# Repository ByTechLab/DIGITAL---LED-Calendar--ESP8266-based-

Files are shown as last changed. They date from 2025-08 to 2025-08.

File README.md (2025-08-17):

<div align="center">
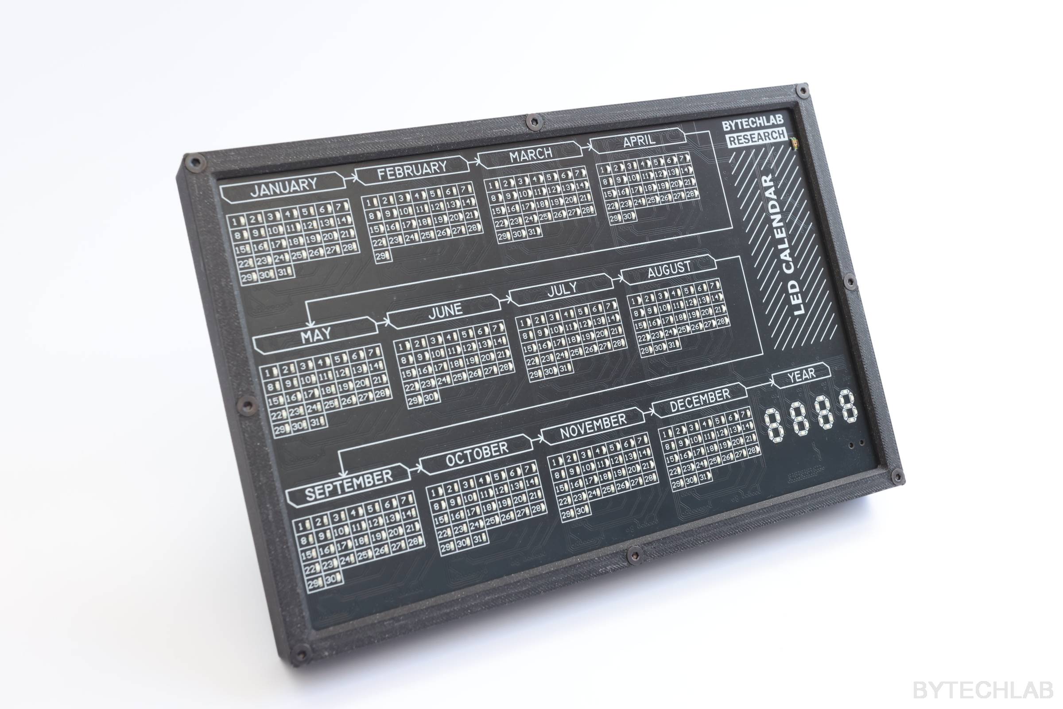
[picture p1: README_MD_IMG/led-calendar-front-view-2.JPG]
project photo
    
</div>

ESP8266 based LED calendar.

### Read more at BYTECHLAB:

<table style="width: 100%; border: none;" cellspacing="0" cellpadding="0" border="0">
  <tr>
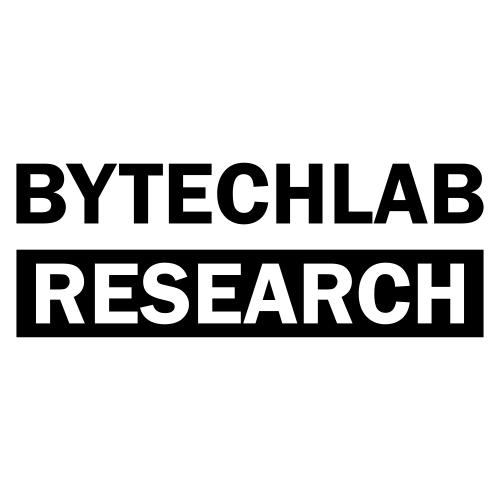
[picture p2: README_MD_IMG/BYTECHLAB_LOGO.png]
    <td></td>
    <td>https://bytechlab.com/2024/10/led-calendar-esp8266-based/</td>
  </tr>
</table>

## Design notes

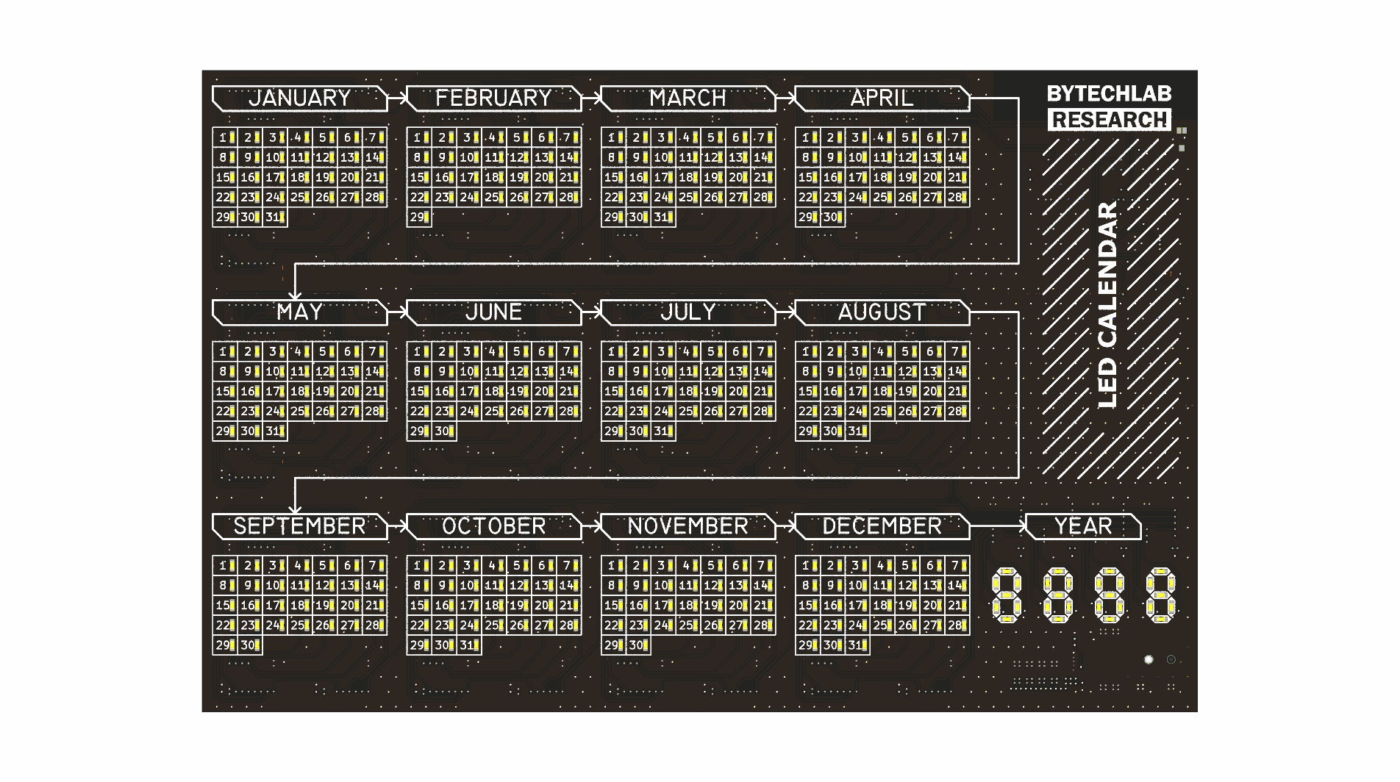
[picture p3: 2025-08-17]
PROJECT_FILES/ECAD/1_REV1_KICAD/_EXPORTED_RENDERS/PCB_LED_CALENDAR_TOP.png

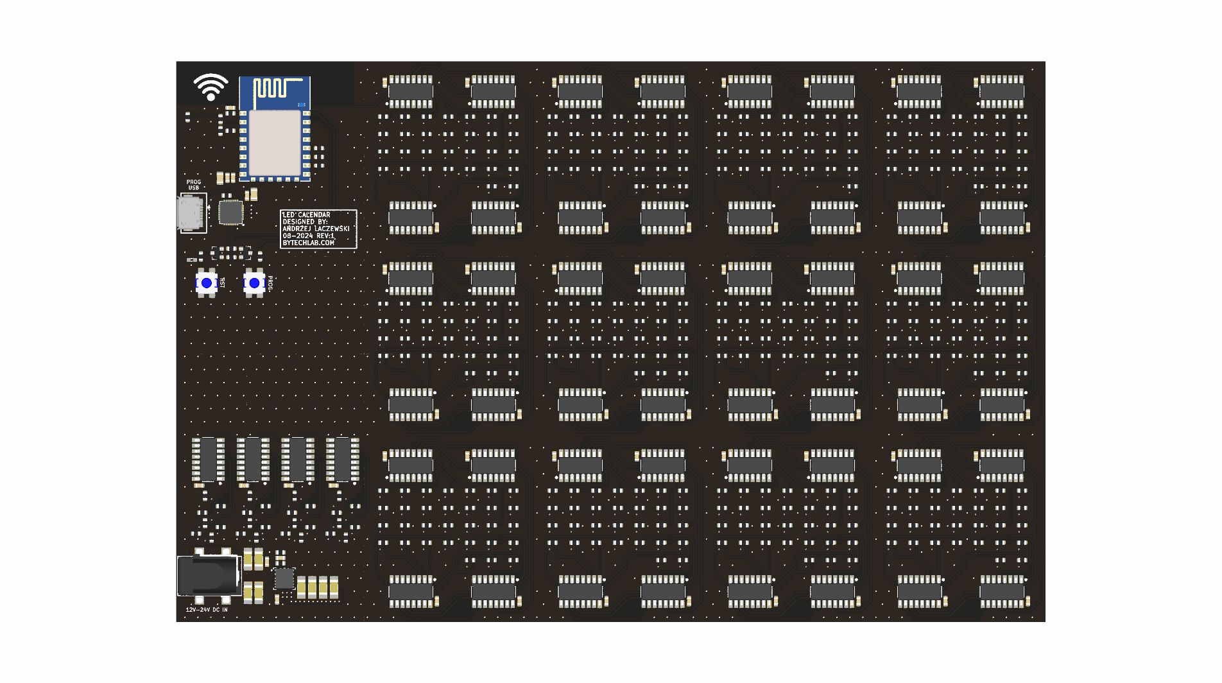
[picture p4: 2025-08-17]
PROJECT_FILES/ECAD/1_REV1_KICAD/_EXPORTED_RENDERS/PCB_LED_CALENDAR_BOTTOM.png

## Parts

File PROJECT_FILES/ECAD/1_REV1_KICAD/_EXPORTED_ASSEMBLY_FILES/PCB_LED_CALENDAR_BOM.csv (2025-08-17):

Reference | Qty | Manufacturer | Manufacturer Part Number | SCH_FOOTPRINT
C1,C5 | 2 | TDK | CGA4J1X7R1E475K125AC | 0805
C2,C3,C4,C6,C11,C13,C18,C19,C20,C21,C22,C23,C24,C25,C26,C27,C28,C29,C30,C31,C32,C33,C34,C35,C36,C37,C38,C39,C40,C41,C42,C43,C44,C45,C46,C47,C48,C49,C50,C51,C52,C53,C54,C55,C56,C57,C58,C59,C60,C61,C62,C63,C64,C65,C66,C67,C68,C69 | 58 | Samsung | CL10B104JB8NNNC | 0603
C7,C8,C9,C10,C14,C15 | 6 | Murata | GRT31CR61H106KE01L | 1206
C16,C17 | 2 | TDK | C3216X5R1E476M160AC | 1206
D1,D2,D3,D4,D5,D6,D7,D8,D9,D10,D11,D12,D13,D14,D15,D16,D17,D18,D19,D20,D21,D22,D23,D24,D25,D26,D27,D28,D29,D30,D31,D32,D33,D34,D35,D36,D37,D38,D39,D40,D41,D42,D43,D44,D45,D46,D47,D48,D49,D50,D51,D52,D53,D54,D55,D56,D57,D58,D59,D60,D61,D62,D63,D64,D65,D66,D67,D68,D69,D70,D71,D72,D73,D74,D75,D76,D77,D78,D79,D80,D81,D82,D83,D84,D85,D86,D87,D88,D89,D90,D91,D92,D93,D94,D95,D96,D97,D98,D99,D100,D101,D102,D103,D104,D105,D106,D107,D108,D109,D110,D111,D112,D113,D114,D115,D116,D117,D118,D119,D120,D121,D122,D123,D124,D125,D126,D127,D128,D129,D130,D131,D132,D133,D134,D135,D136,D137,D138,D139,D140,D141,D142,D143,D144,D145,D146,D147,D148,D149,D150,D151,D152,D153,D154,D155,D156,D157,D158,D159,D160,D161,D162,D163,D164,D165,D166,D167,D168,D169,D170,D171,D172,D173,D174,D175,D176,D177,D178,D179,D180,D181,D182,D183,D184,D185,D186,D187,D188,D189,D190,D191,D192,D193,D194,D195,D196,D197,D198,D199,D200,D201,D202,D203,D204,D205,D206,D207,D208,D209,D210,D211,D212,D213,D214,D215,D216,D217,D218,D219,D220,D221,D222,D223,D224,D225,D226,D227,D228,D229,D230,D231,D232,D233,D234,D235,D236,D237,D238,D239,D240,D241,D242,D243,D244,D245,D246,D247,D248,D249,D250,D251,D252,D253,D254,D255,D256,D257,D258,D259,D260,D261,D262,D263,D264,D265,D266,D267,D268,D269,D270,D271,D272,D273,D274,D275,D276,D277,D278,D279,D280,D281,D282,D283,D284,D285,D286,D287,D288,D289,D290,D291,D292,D293,D294,D295,D296,D297,D298,D299,D300,D301,D302,D303,D304,D305,D306,D307,D308,D309,D310,D311,D312,D313,D314,D315,D316,D317,D318,D319,D320,D321,D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 | 400 | Foshan NationStar Optoelectronics | NCD0603O1 | 0603
J1 | 1 | Molex | 47346-0001 | MICRO USB
MOD1 | 1 | Ai-thinker | ESP-12E | ESP-12E
P1 | 1 | GCT | DCJ250-05-A-K1-A | DC JACK
Q1,Q2 | 2 | FUXINSEMI | S8050 | SOT23
QL1 | 1 | Vishay Intertech | TEMT6000X01 | 1206
R1,R15 | 2 | Vishay | CRCW060310K0FKTA | 0603
R2 | 1 | Vishay | CRCW0603220KFKTABC | 0603
R3 | 1 | Royalohm | 0603SAF1003T5E | 0603
R4,R5,R6,R9,R11,R12,R13 | 7 | Yageo | RC0603FR-0712KL | 0603
R8,R10 | 2 | Yageo | RC0603FR-07470RL | 0603
R14 | 1 | Vishay | CRCW06031K00FKEA | 0603
R16 | 1 | Vishay | RV0603E2211BNT | 0603
R17,R18,R19,R20,R21,R22,R23,R24,R25,R26,R27,R28,R29,R30,R31,R32,R33,R34,R35,R36,R37,R38,R39,R40,R41,R42,R43,R44,R45,R46,R47,R48,R49,R50,R51,R52,R53,R54,R55,R56,R57,R58,R59,R60,R61,R62,R63,R64,R65,R66,R67,R68,R69,R70,R71,R72,R73,R74,R75,R76,R77,R78,R79,R80,R81,R82,R83,R84,R85,R86,R87,R88,R89,R90,R91,R92,R93,R94,R95,R96,R97,R98,R99,R100,R101,R102,R103,R104,R105,R106,R107,R108,R109,R110,R111,R112,R113,R114,R115,R116,R117,R118,R119,R120,R121,R122,R123,R124,R125,R126,R127,R128,R129,R130,R131,R132,R133,R134,R135,R136,R137,R138,R139,R140,R141,R142,R143,R144,R145,R146,R147,R148,R149,R150,R151,R152,R153,R154,R155,R156,R157,R158,R159,R160,R161,R162,R163,R164,R165,R166,R167,R168,R169,R170,R171,R172,R173,R174,R175,R176,R177,R178,R179,R180,R181,R182,R183,R184,R185,R186,R187,R188,R189,R190,R191,R192,R193,R194,R195,R196,R197,R198,R199,R200,R201,R202,R203,R204,R205,R206,R207,R208,R209,R210,R211,R212,R213,R214,R215,R216,R217,R218,R219,R220,R221,R222,R223,R224,R225,R226,R227,R228,R229,R230,R231,R232,R233,R234,R235,R236,R237,R238,R239,R240,R241,R242,R243,R244,R245,R246,R247,R248,R249,R250,R251,R252,R253,R254,R255,R256,R257,R258,R259,R260,R261,R262,R263,R264,R265,R266,R267,R268,R269,R270,R271,R272,R273,R274,R275,R276,R277,R278,R279,R280,R281,R282,R283,R284,R285,R286,R287,R288,R289,R290,R291,R292,R293,R294,R295,R296,R297,R298,R299,R300,R301,R302,R303,R304,R305,R306,R307,R308,R309,R310,R311,R312,R313,R314,R315,R316,R317,R318,R319,R320,R321,R322,R323,R324,R325,R326,R327,R328,R329,R330,R331,R332,R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 | 400 | Yageo | RC0603FR-07300RL | 0603
S1,S2 | 2 | BOURNS | 7914G-1-000E | SMD TACT SWITCH
U1 | 1 | SKYWORKS/SILICON LABS | CP2102N-A02-GQFN28R | QFN28
U2 | 1 | Texas Instruments | TPSM84209RKHT | QFN9_4.5x4
U3,U4,U5,U6,U7,U8,U9,U10,U11,U12,U13,U14,U15,U16,U17,U18,U19,U20,U21,U22,U23,U24,U25,U26,U27,U28,U29,U30,U31,U32,U33,U34,U35,U36,U37,U38,U39,U40,U41,U42,U43,U44,U45,U46,U47,U48,U49,U50,U51,U52,U53,U54 | 52 | Nexperia | 74HC595D,118 | SO16

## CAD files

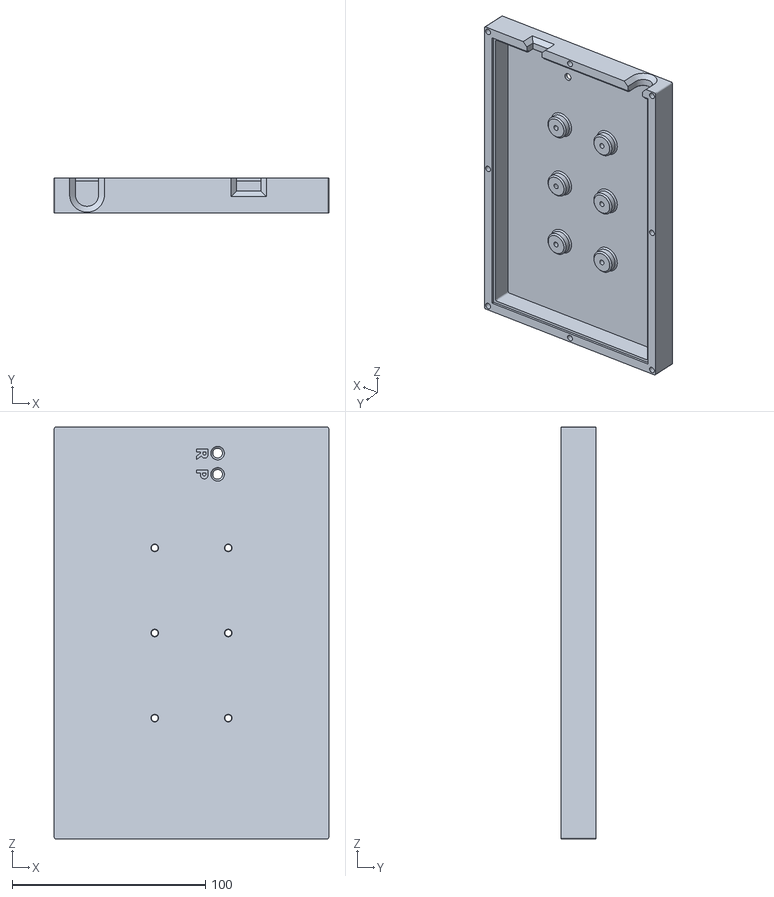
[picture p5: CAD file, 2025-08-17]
PROJECT_FILES/MCAD/2_REV2_KICAD/_STL_EXPORTED/3DP_PLA_Back_Cover.stl
142.0 x 18.0 x 213.0

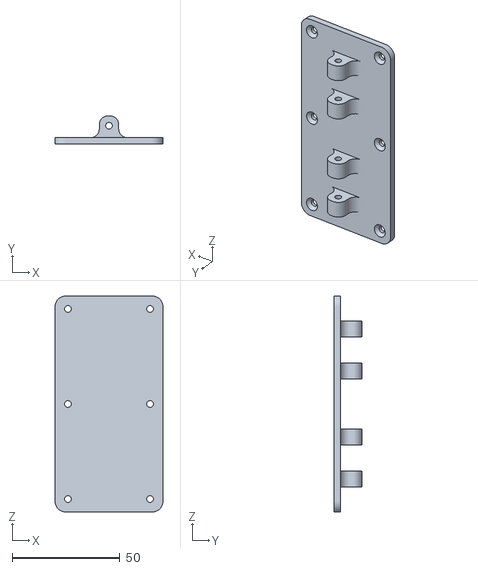
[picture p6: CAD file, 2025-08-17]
PROJECT_FILES/MCAD/2_REV2_KICAD/_STL_EXPORTED/3DP_PLA_Stand_Leg_Mount.stl
50.0 x 13.0 x 100.0

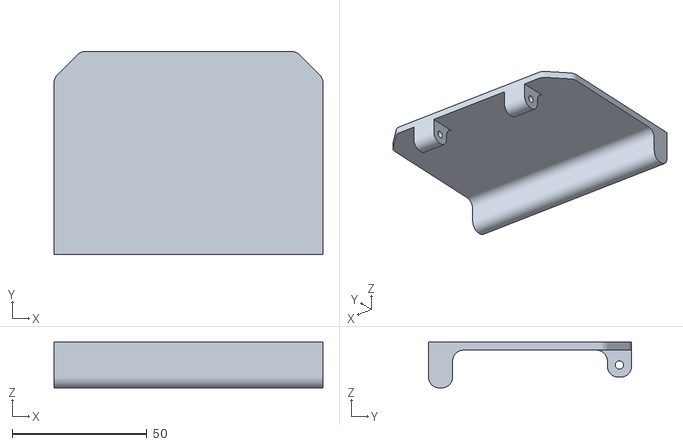
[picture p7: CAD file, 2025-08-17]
PROJECT_FILES/MCAD/2_REV2_KICAD/_STL_EXPORTED/3DP_PLA_Stand_Leg.stl
100.0 x 75.5 x 17.0

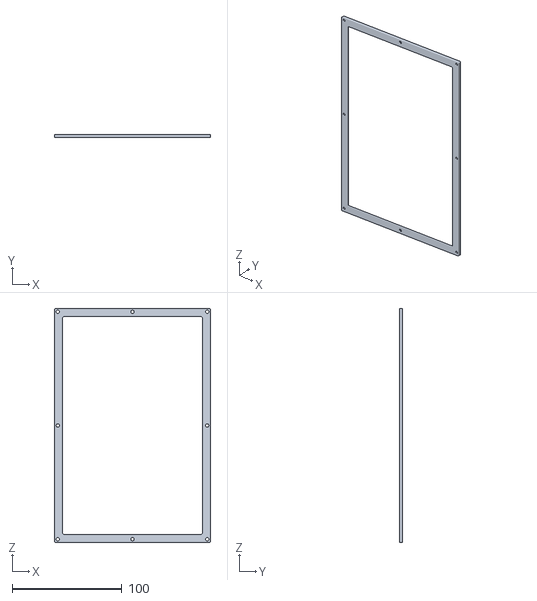
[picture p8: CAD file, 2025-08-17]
PROJECT_FILES/MCAD/2_REV2_KICAD/_STL_EXPORTED/3DP_PLA_Front_Mounting_Bracket.stl
142.0 x 3.00 x 213.0

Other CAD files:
PROJECT_FILES/MCAD/2_REV2_KICAD/ASSEMBLY_MAIN_REVA/3DP_PLA_Back_Cover.ipt
PROJECT_FILES/MCAD/2_REV2_KICAD/ASSEMBLY_MAIN_REVA/3DP_PLA_Front_Mounting_Bracket.ipt
PROJECT_FILES/MCAD/2_REV2_KICAD/ASSEMBLY_MAIN_REVA/3DP_PLA_Stand_Leg.ipt
PROJECT_FILES/MCAD/2_REV2_KICAD/ASSEMBLY_MAIN_REVA/3DP_PLA_Stand_Leg_Mount.ipt
PROJECT_FILES/MCAD/2_REV2_KICAD/ASSEMBLY_MAIN_REVA/ASSEMBLY_Main.iam
PROJECT_FILES/MCAD/2_REV2_KICAD/__CONTENT_CENTER_PARTS/DIN 125-2 A/DIN 125-2 - A 3,2A.ipt
PROJECT_FILES/MCAD/2_REV2_KICAD/__CONTENT_CENTER_PARTS/DIN 7991(2)/DIN 7991 - M3x12.ipt
PROJECT_FILES/MCAD/2_REV2_KICAD/__CONTENT_CENTER_PARTS/DIN 7991(2)/DIN 7991 - M3x8.ipt
PROJECT_FILES/MCAD/2_REV2_KICAD/__CONTENT_CENTER_PARTS/DIN 934/DIN 934 - M3 x 0,5.ipt
PROJECT_FILES/MCAD/2_REV2_KICAD/__CONTENT_CENTER_PARTS/ISO 7380-1/ISO 7380-1 - M3 x 30.ipt
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

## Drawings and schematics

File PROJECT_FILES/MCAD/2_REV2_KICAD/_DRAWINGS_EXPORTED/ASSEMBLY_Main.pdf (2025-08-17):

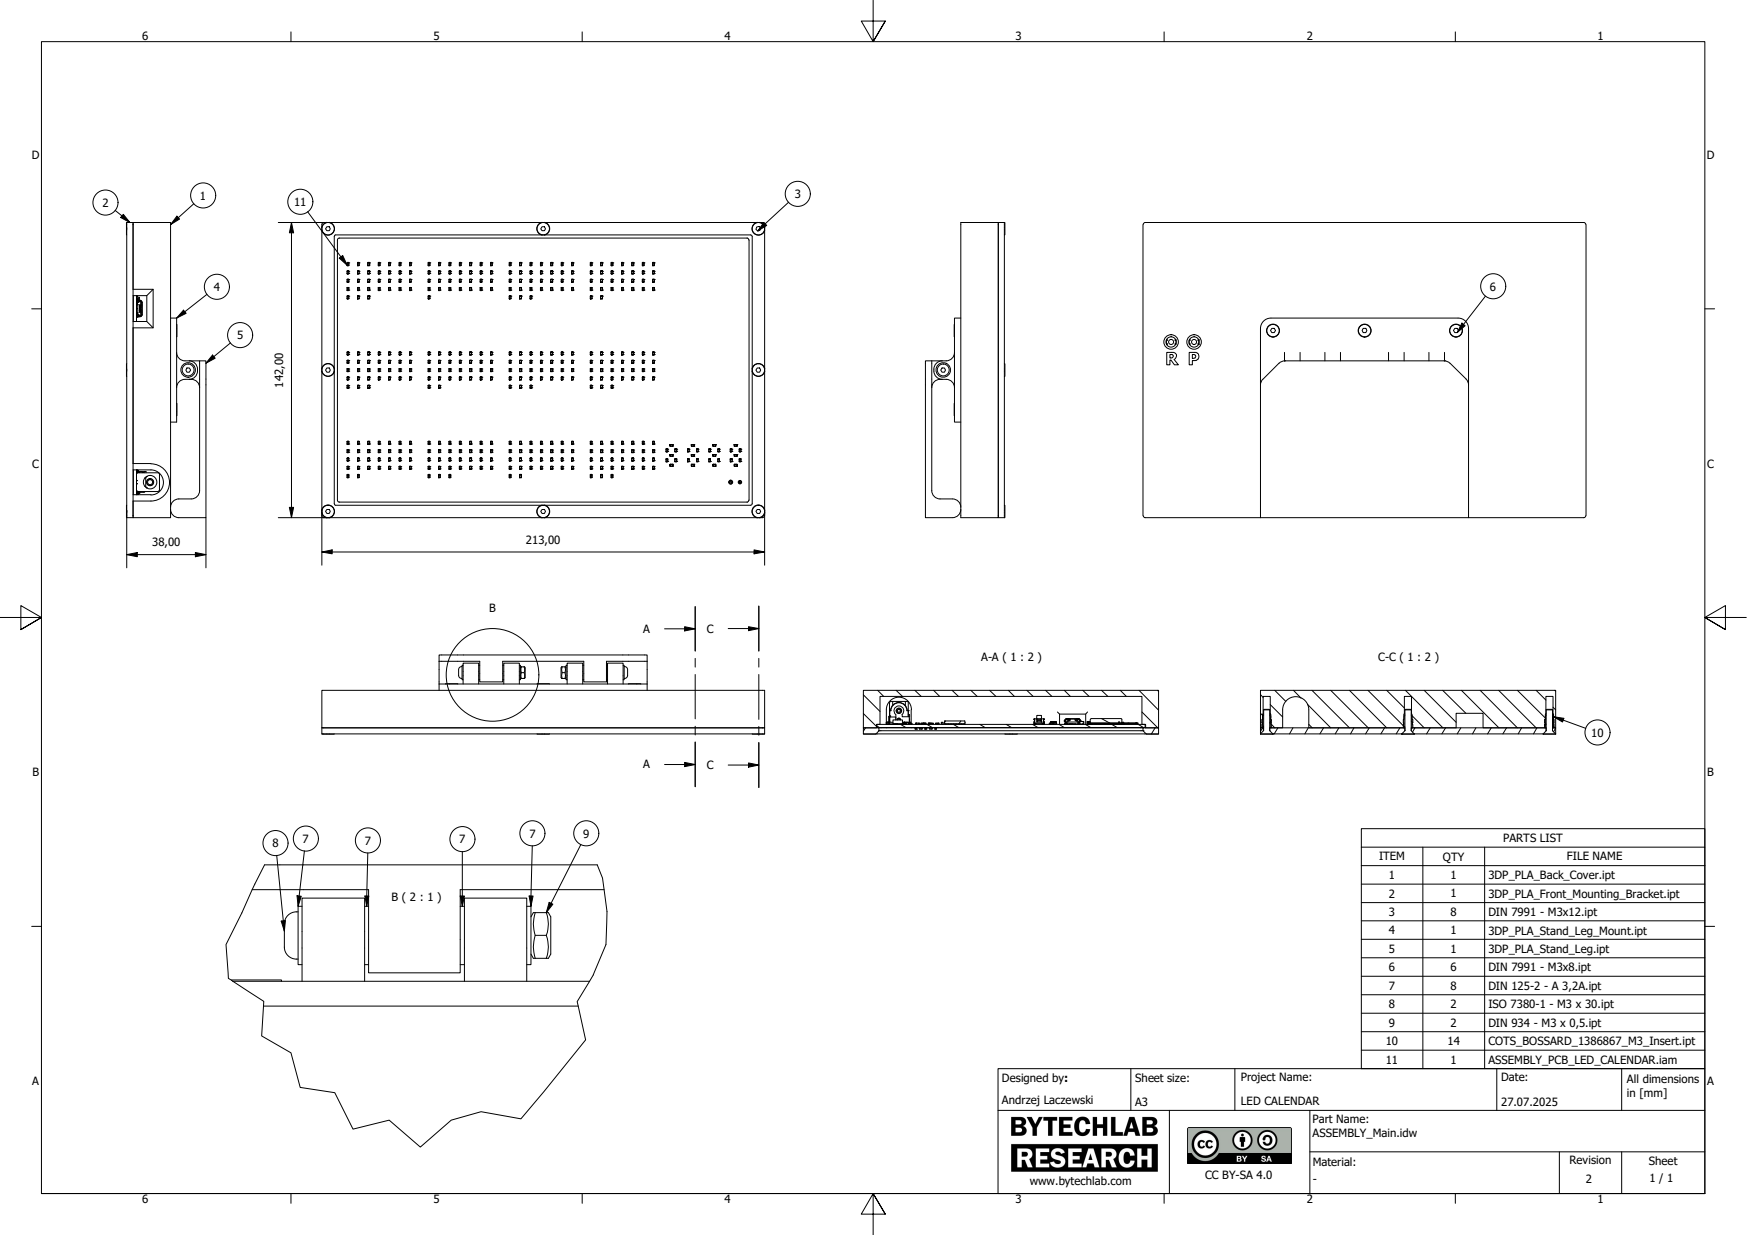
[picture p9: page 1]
PARTS LIST; ITEM; QTY; FILE NAME; DIN 7991 - M3x12.ipt; DIN 7991 - M3x8.ipt; DIN 125-2 - A 3,2A.ipt; ISO 7380-1 - M3 x 30.ipt; DIN 934 - M3 x 0,5.ipt; Andrzej Laczewski; Designed by:; Sheet size:; Date:; Part Name:; All dimensions in [mm]; Project Name:; LED CALENDAR

www.bytechlab.com

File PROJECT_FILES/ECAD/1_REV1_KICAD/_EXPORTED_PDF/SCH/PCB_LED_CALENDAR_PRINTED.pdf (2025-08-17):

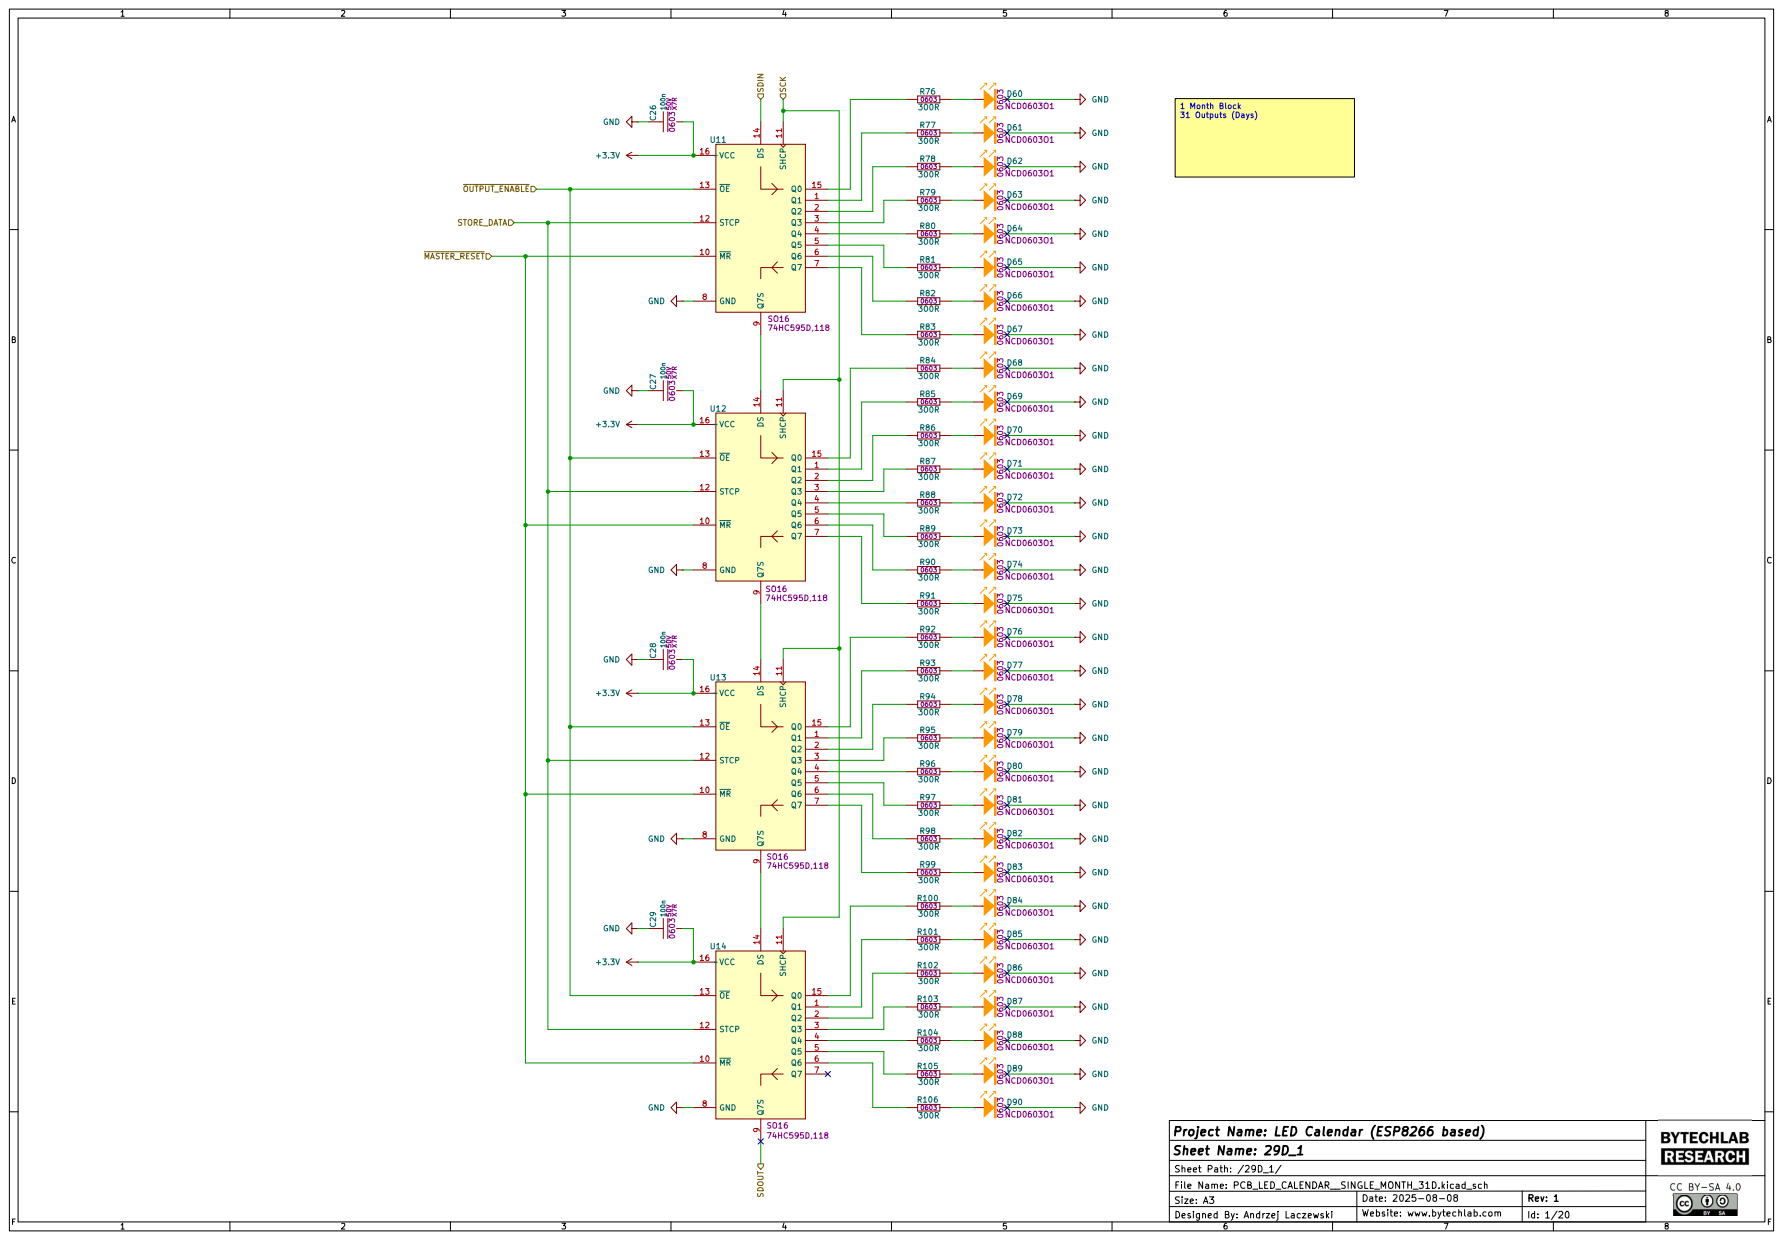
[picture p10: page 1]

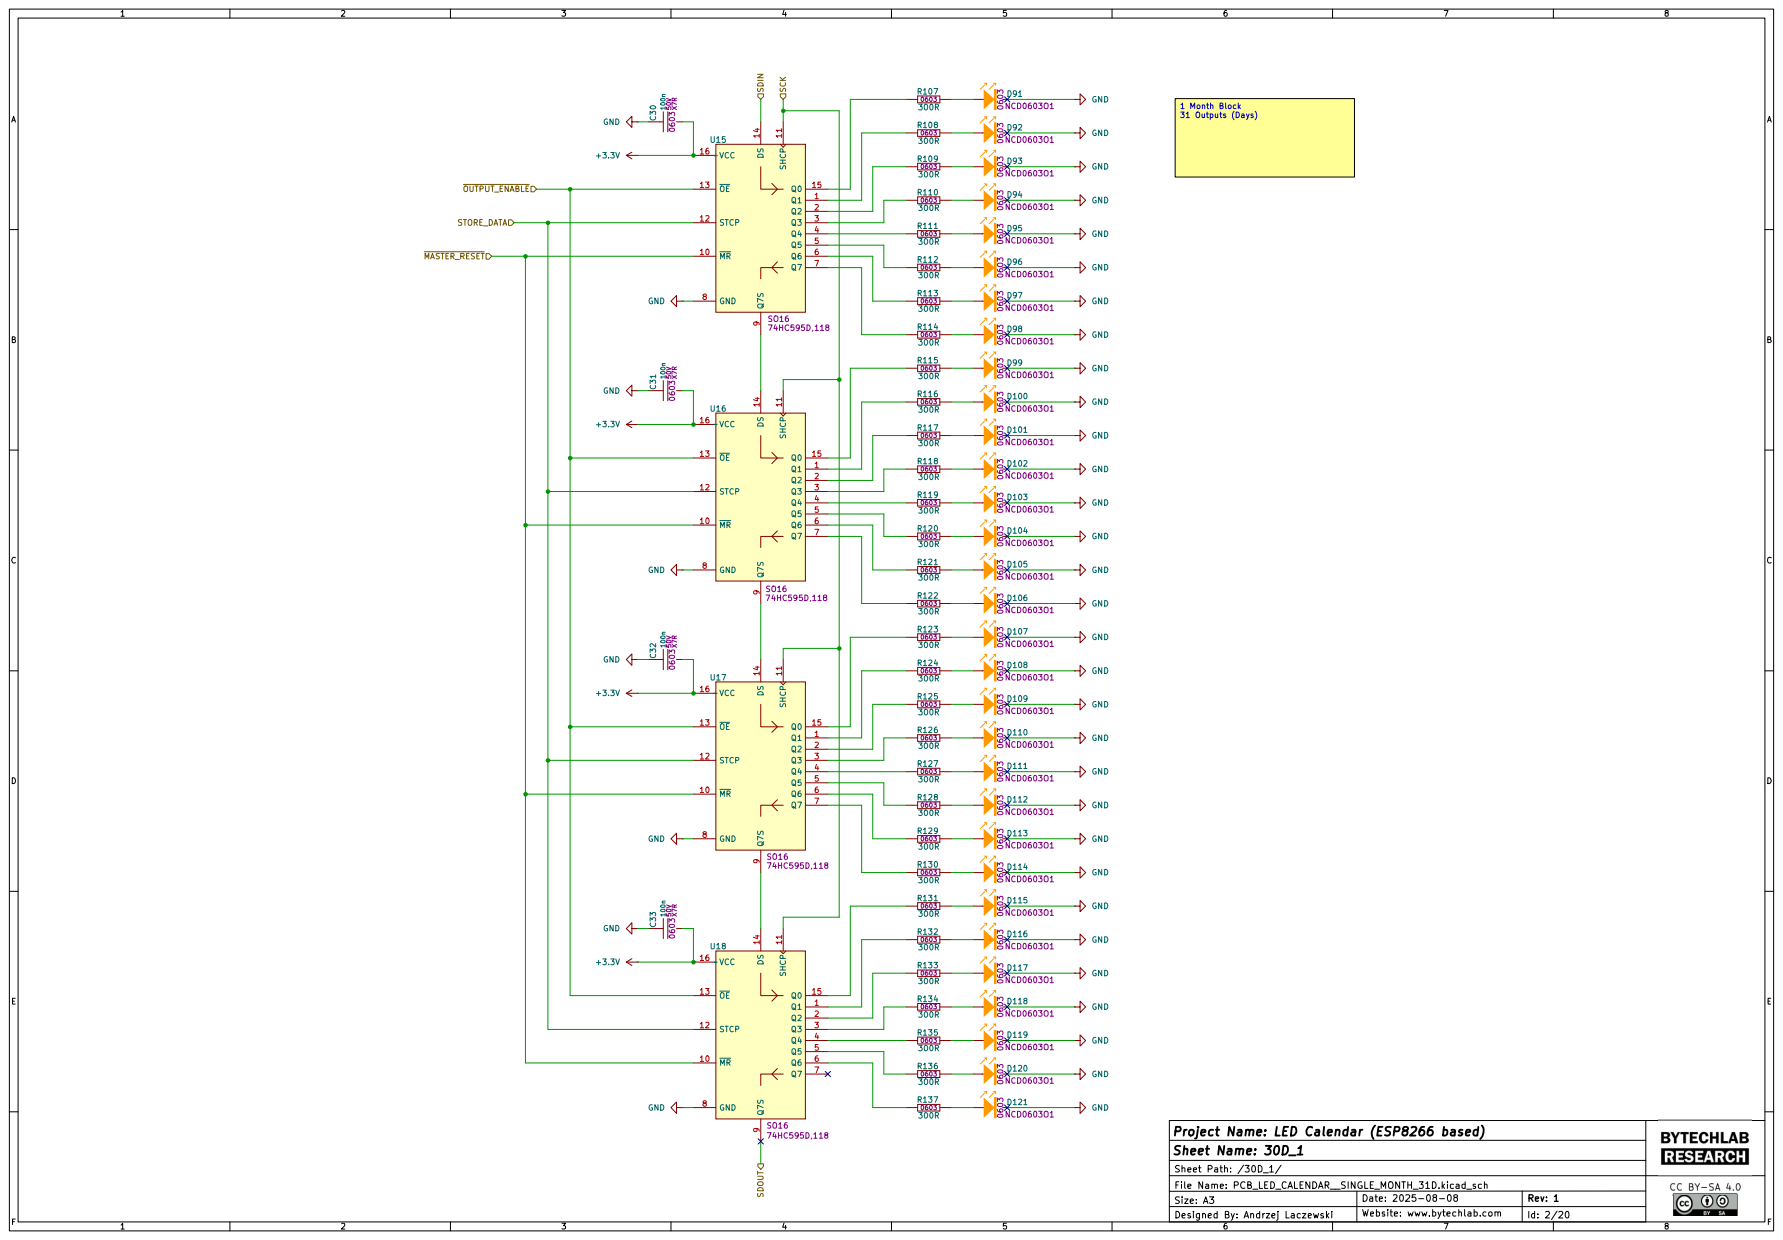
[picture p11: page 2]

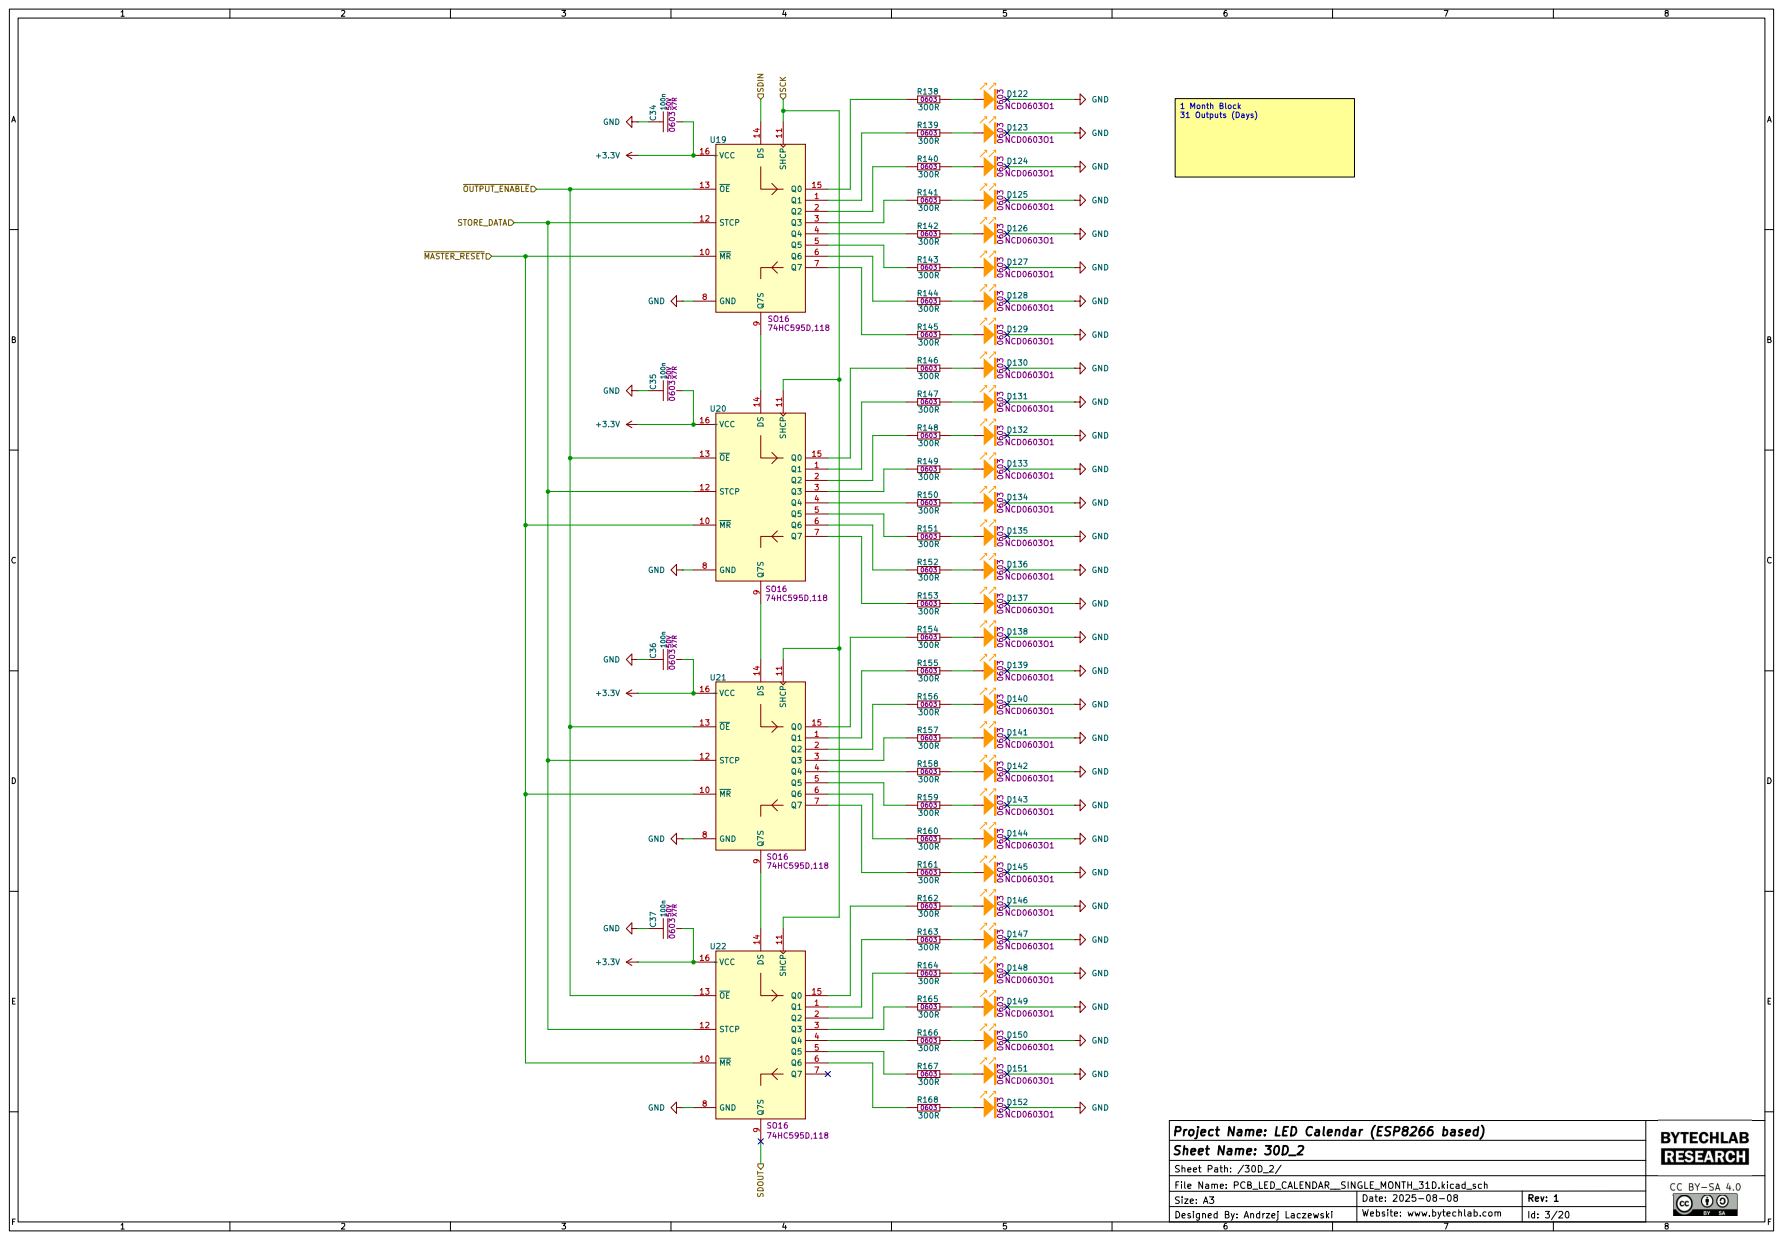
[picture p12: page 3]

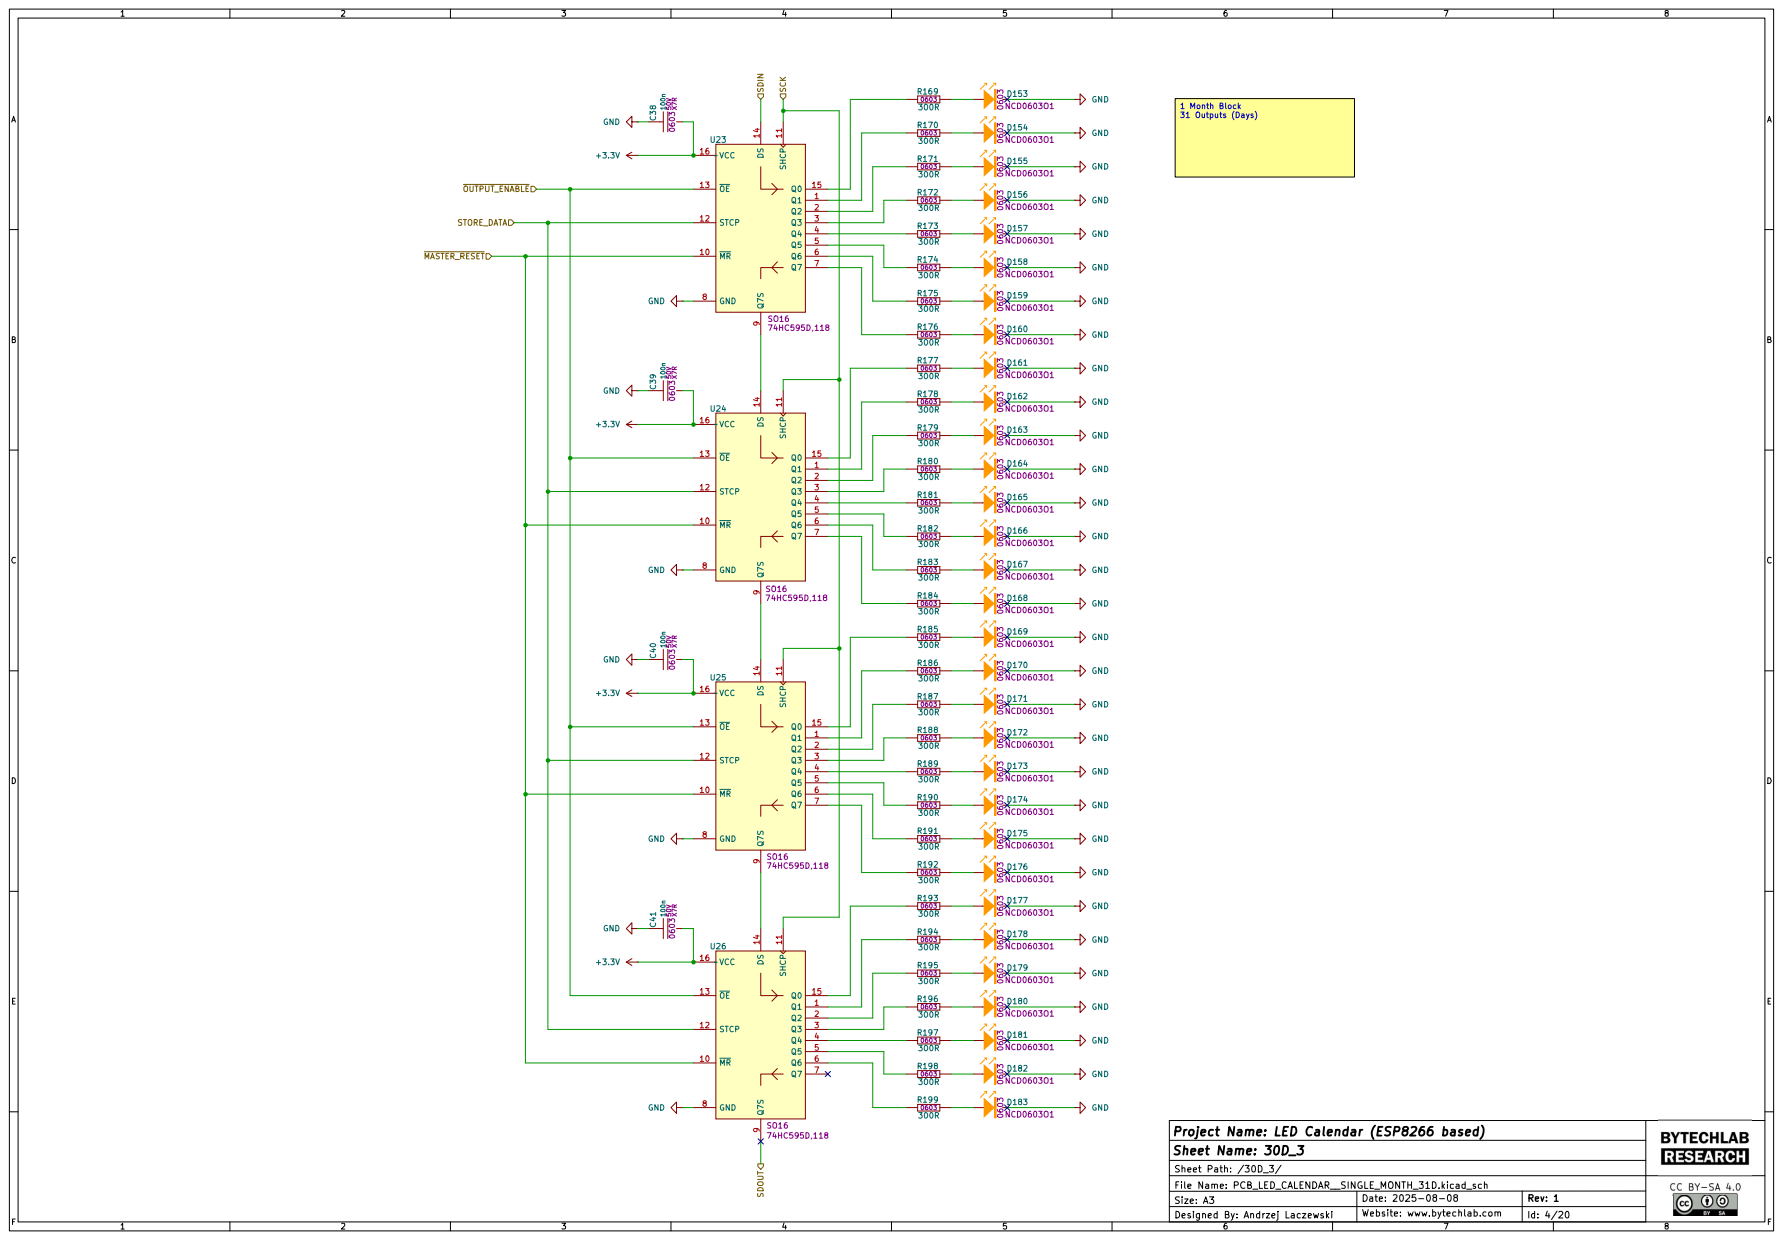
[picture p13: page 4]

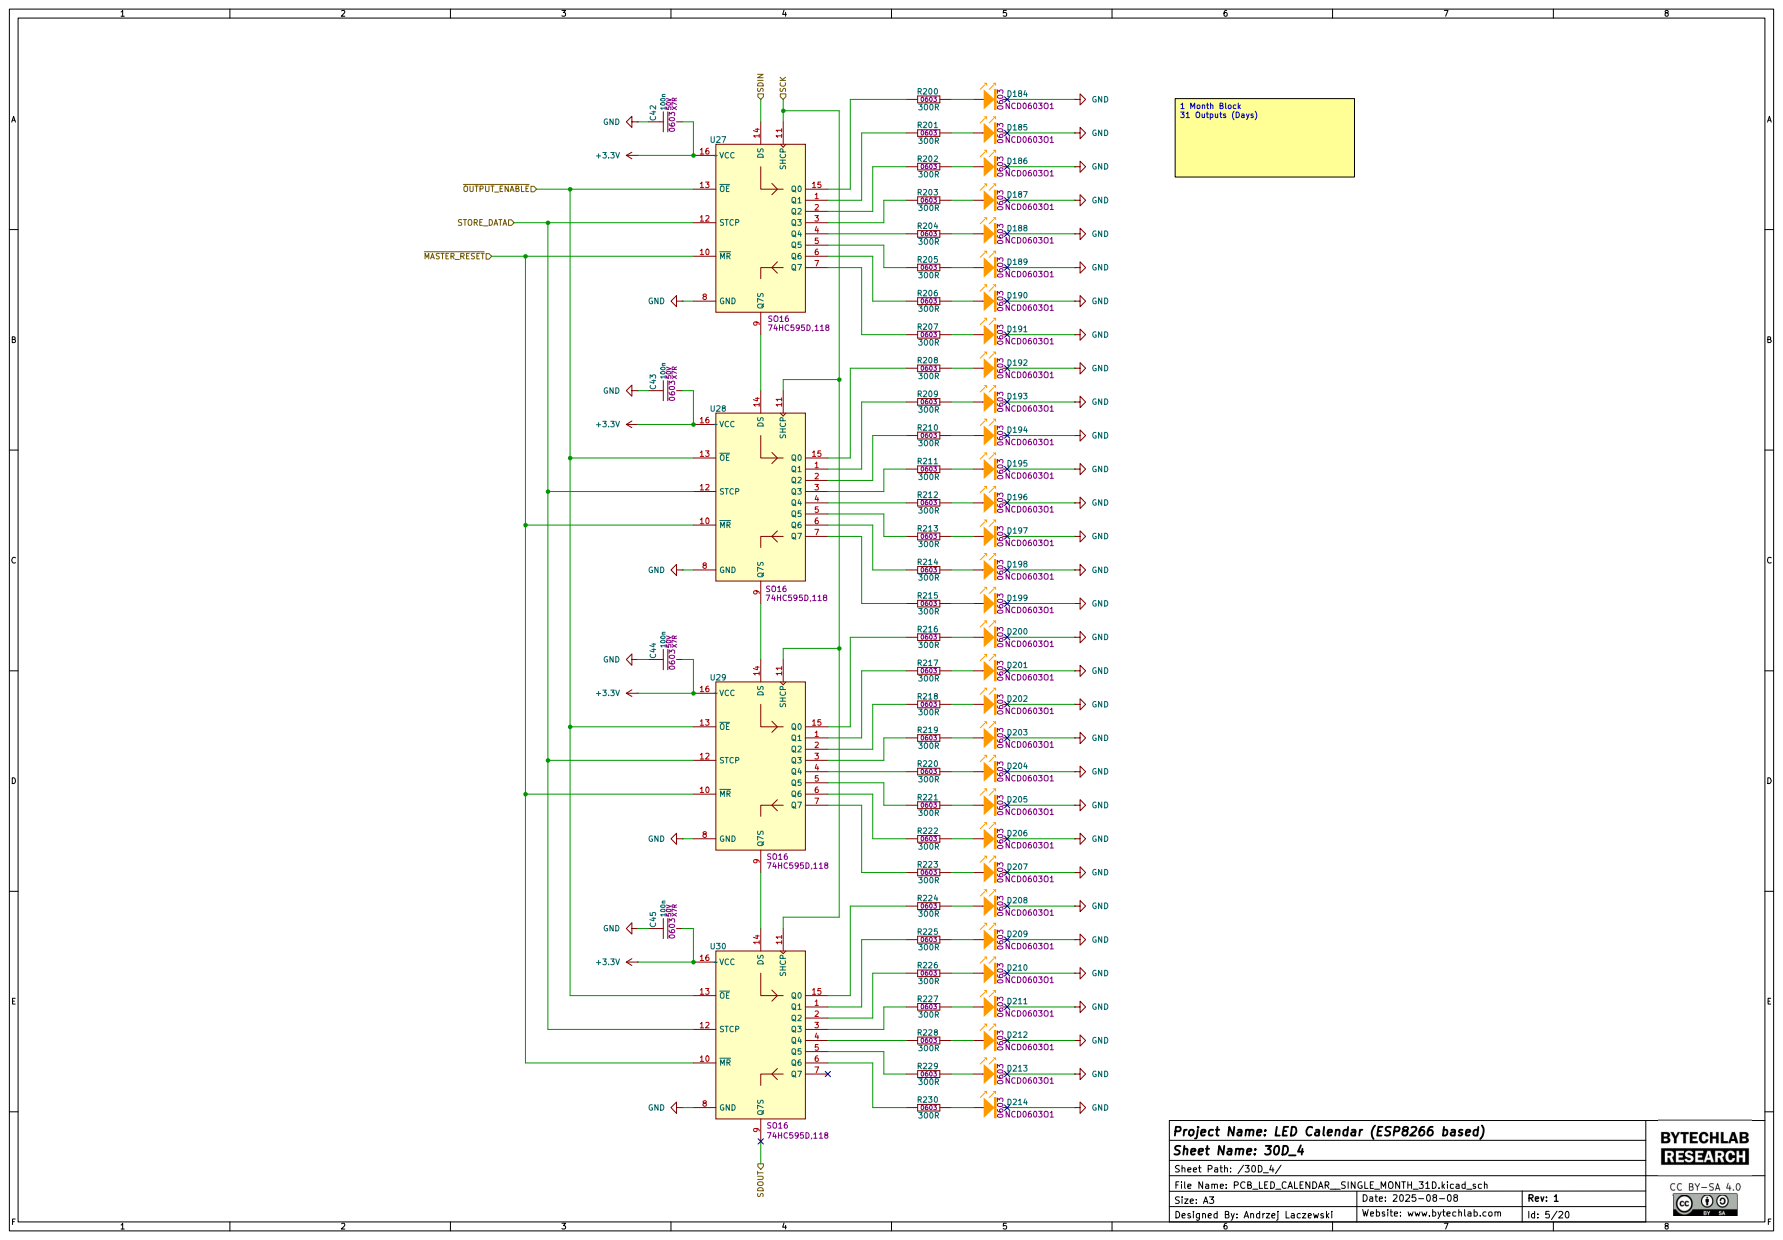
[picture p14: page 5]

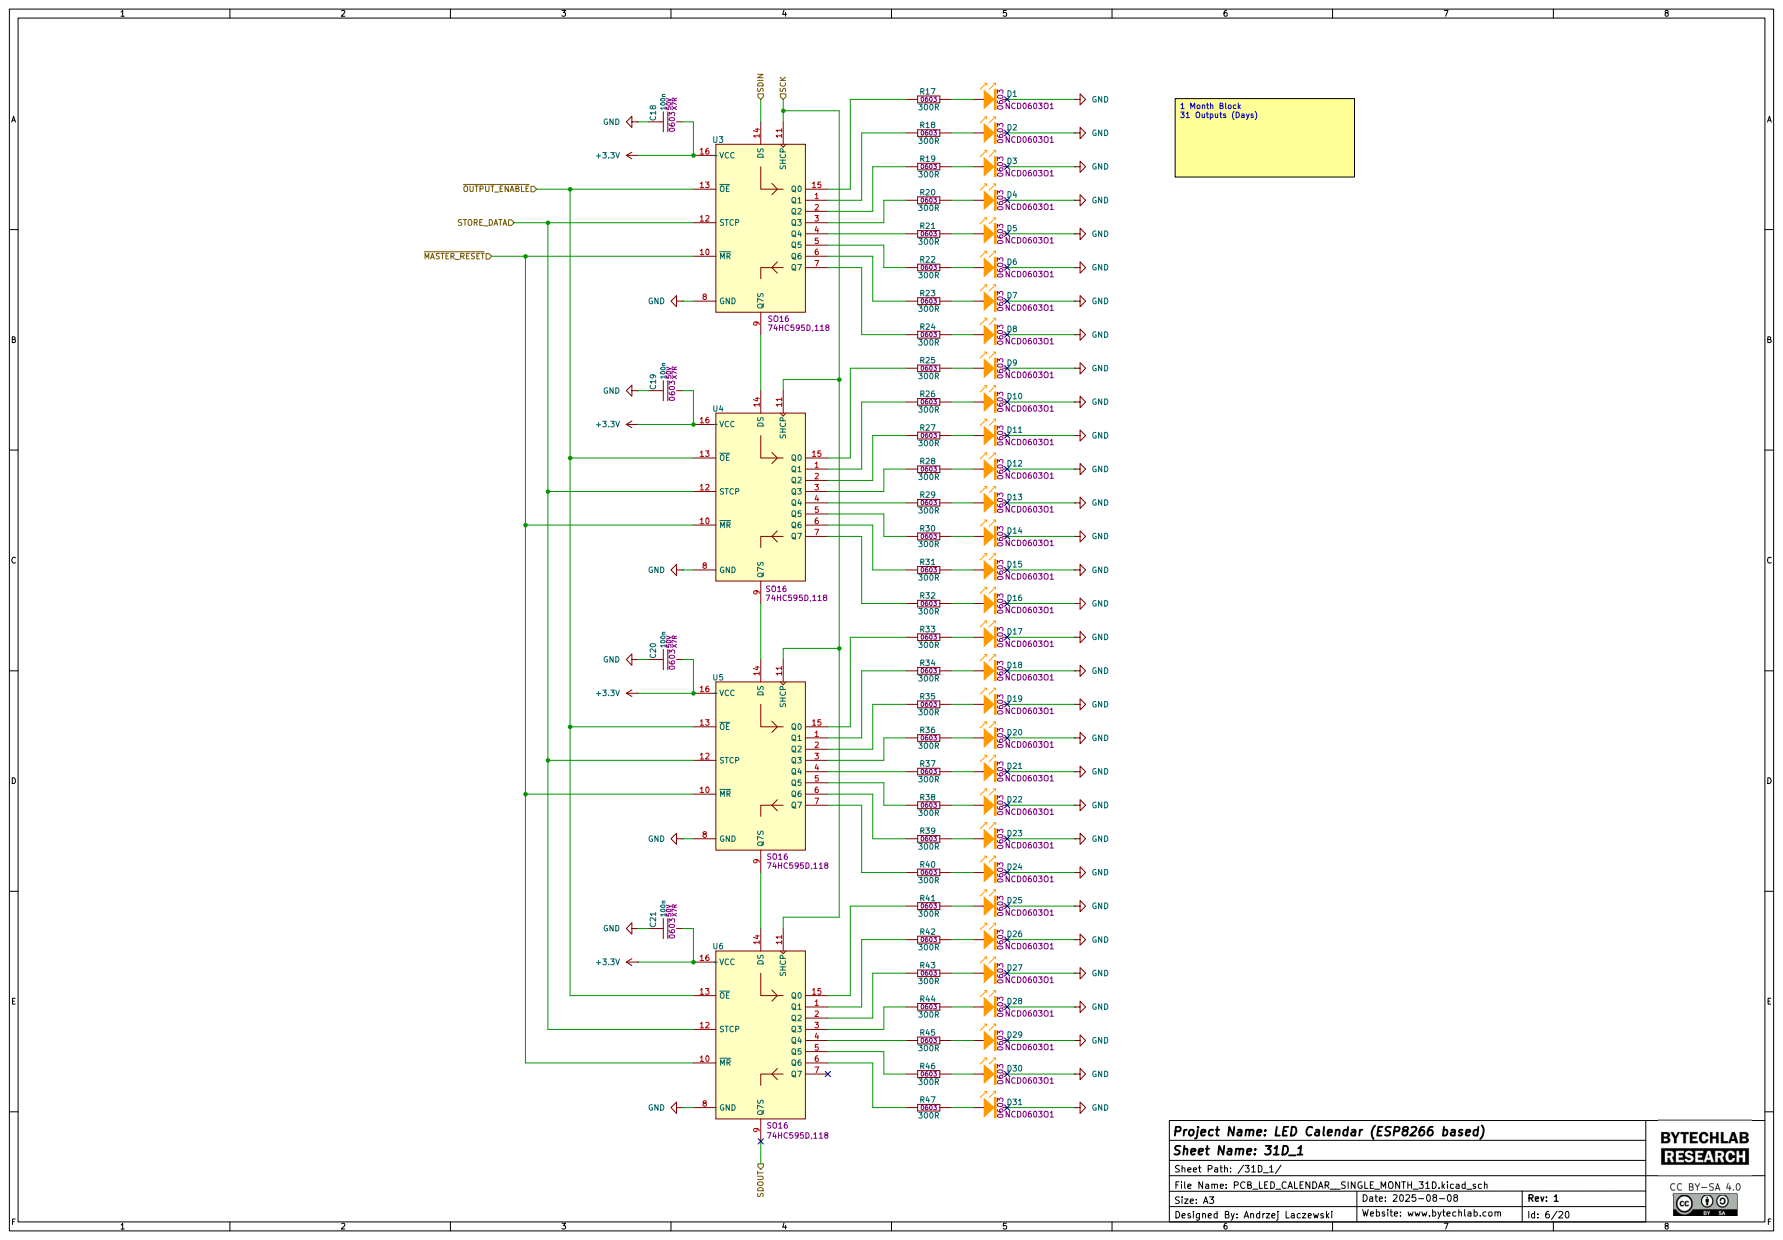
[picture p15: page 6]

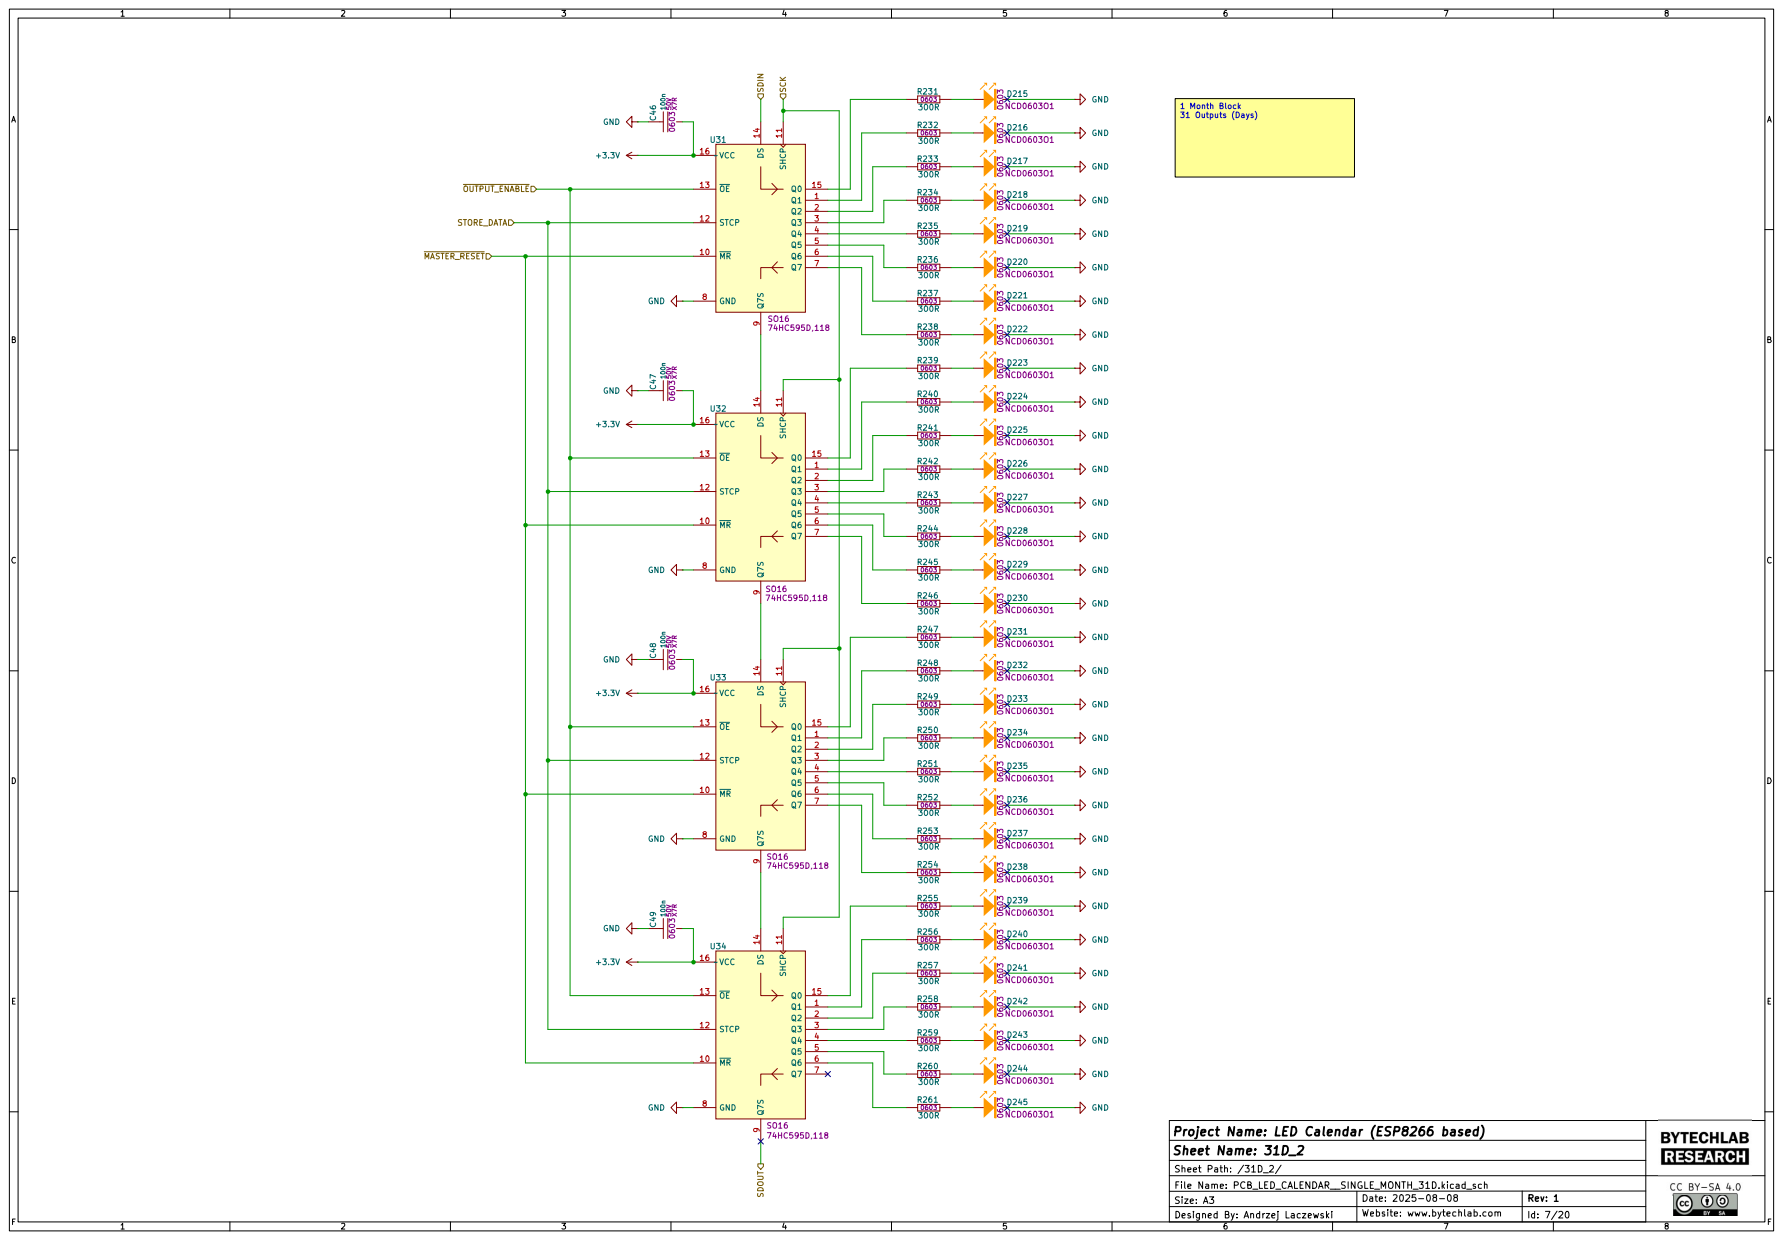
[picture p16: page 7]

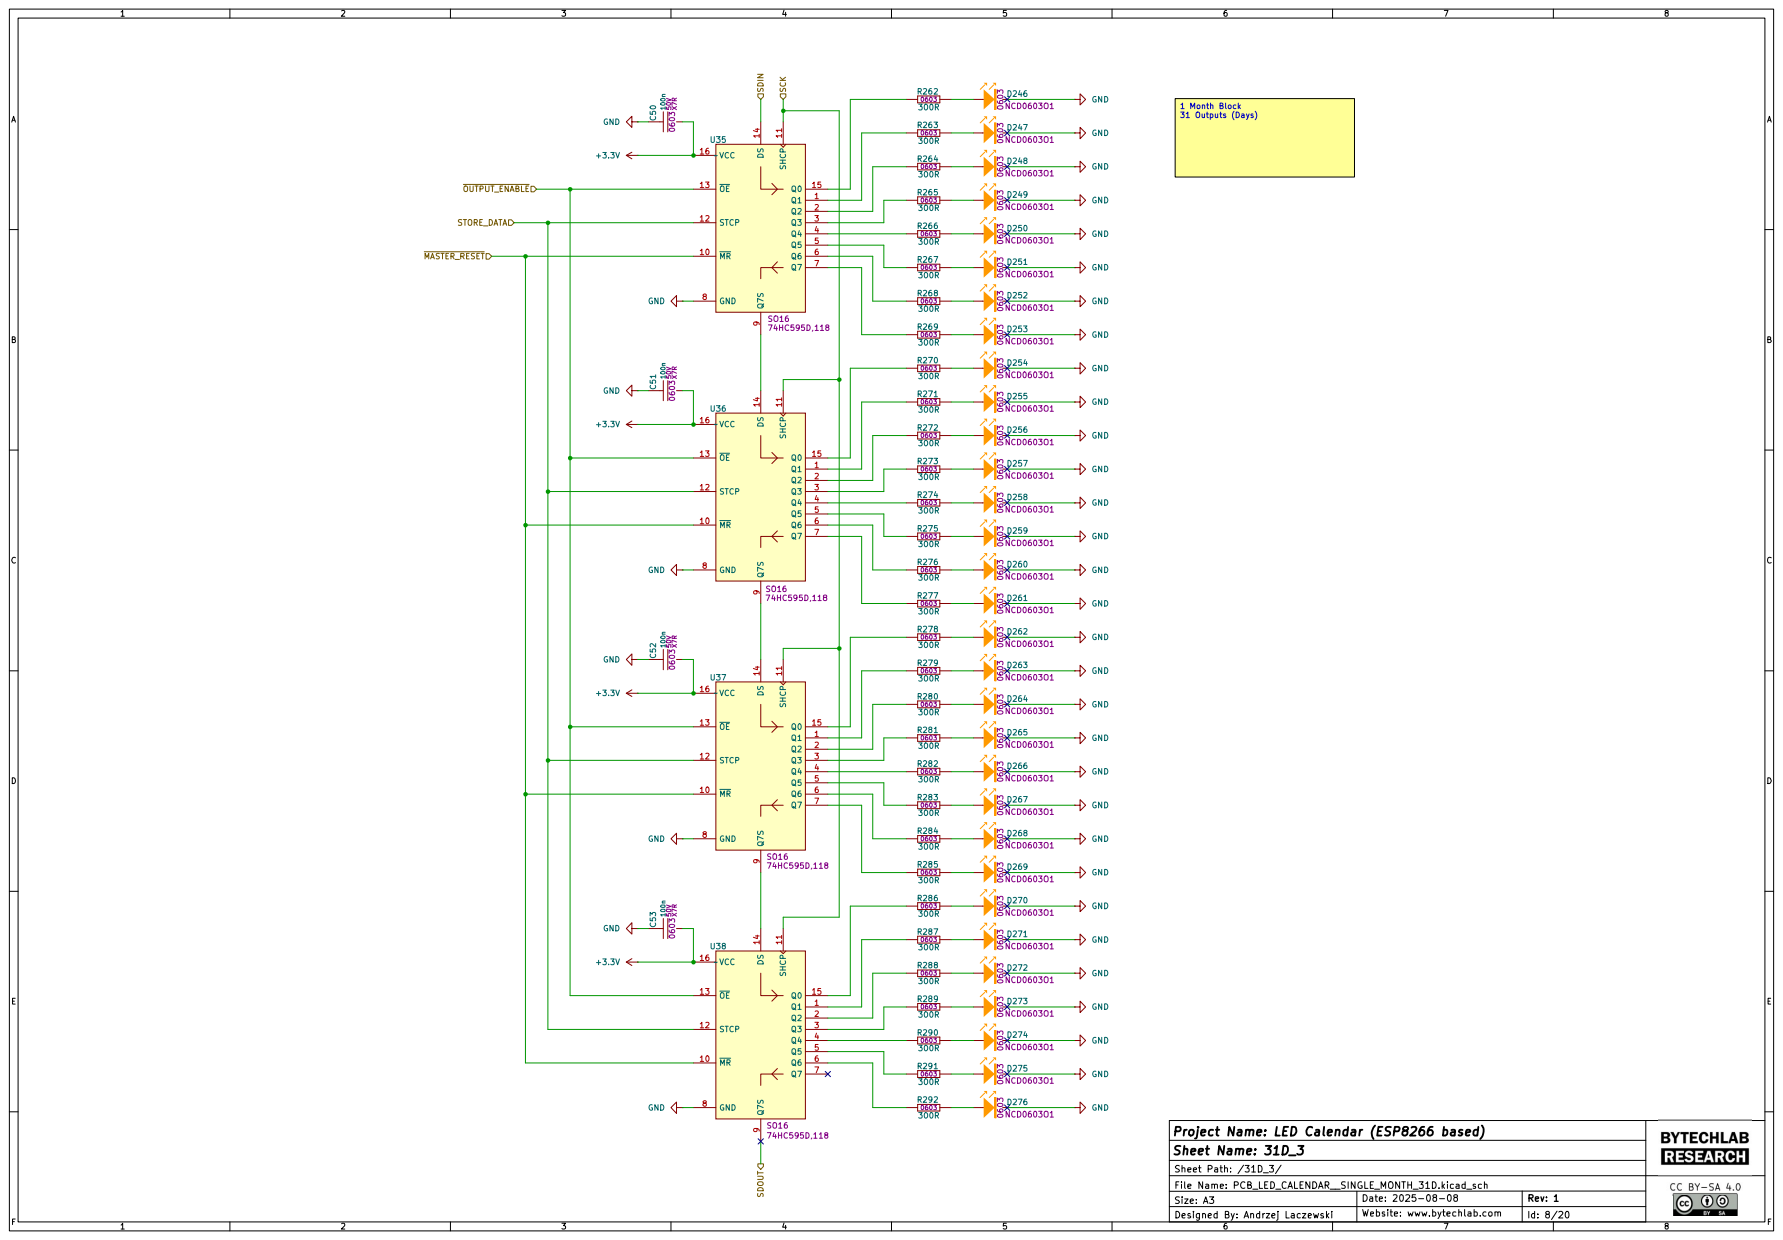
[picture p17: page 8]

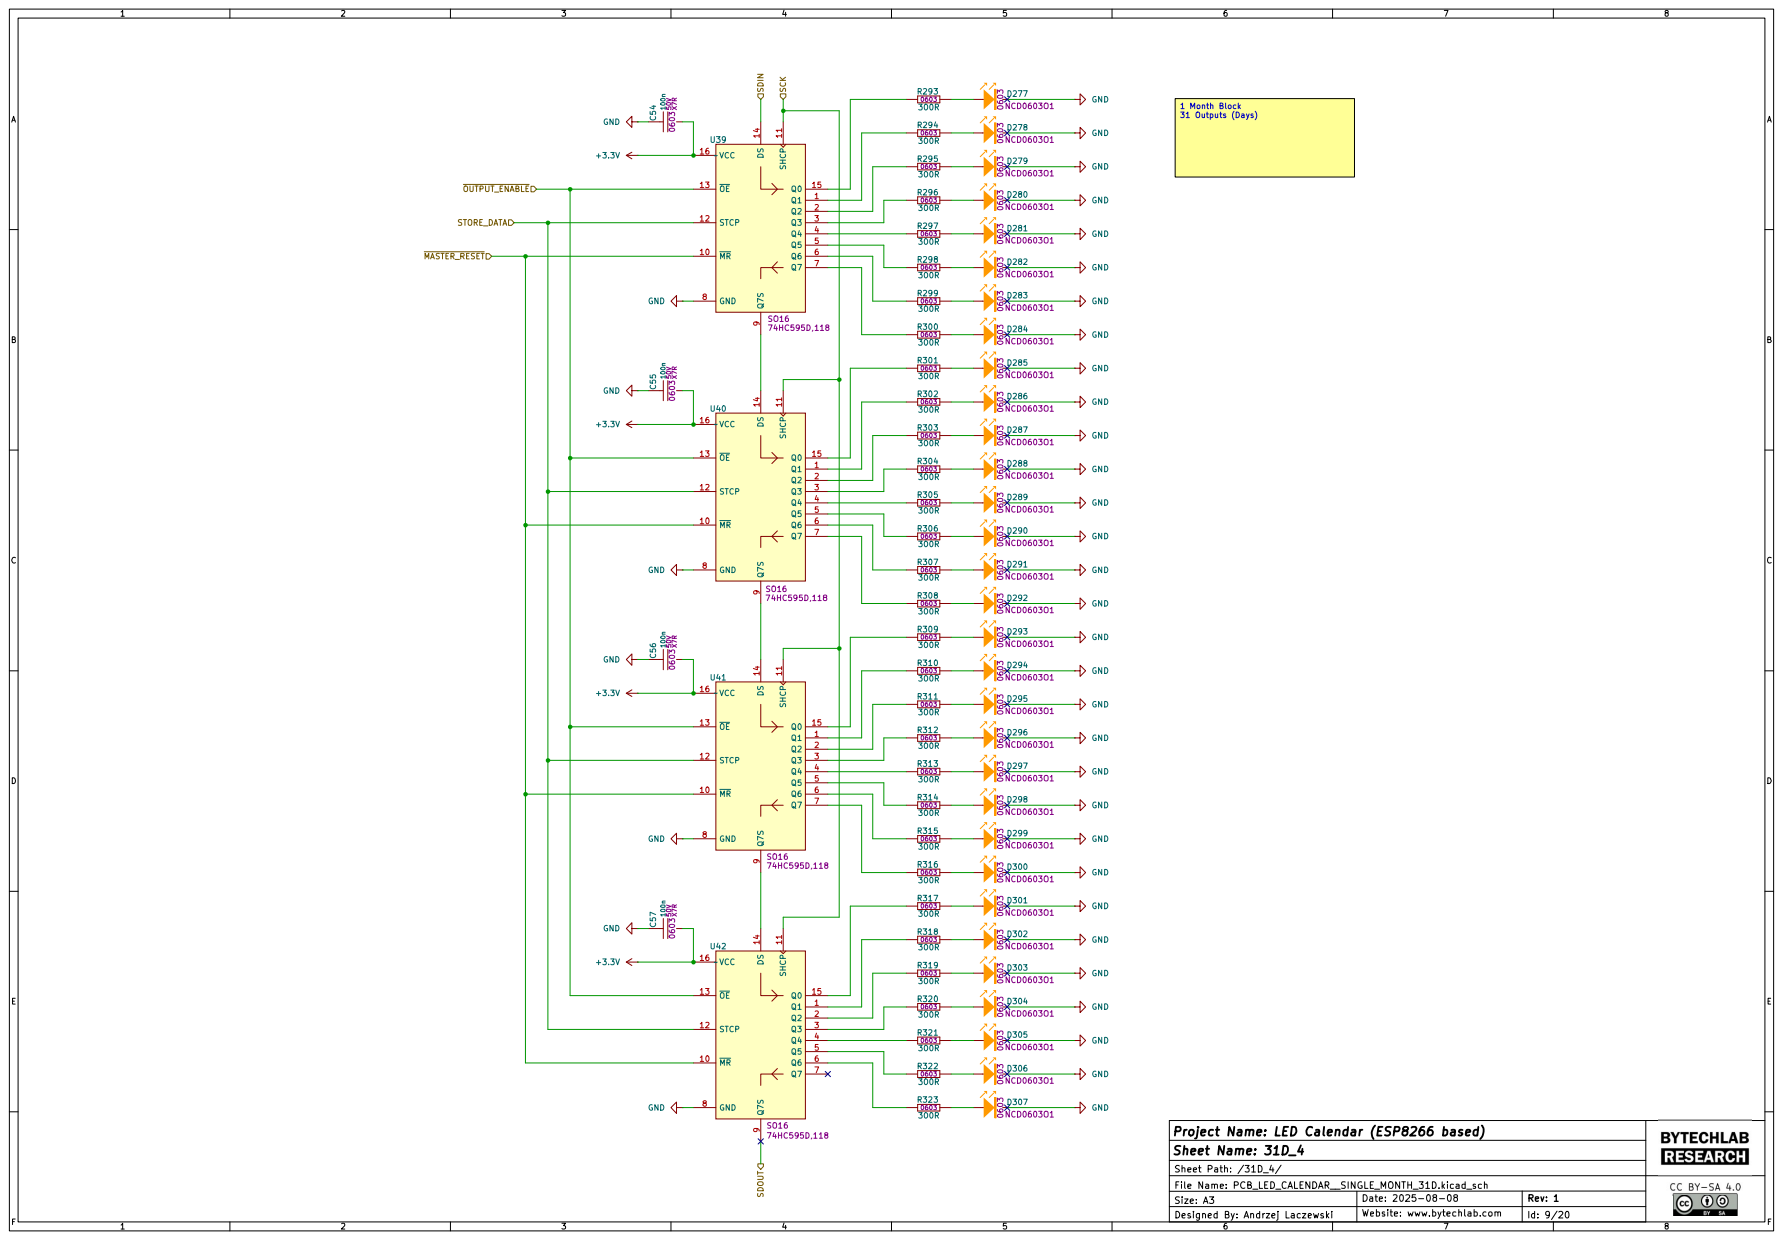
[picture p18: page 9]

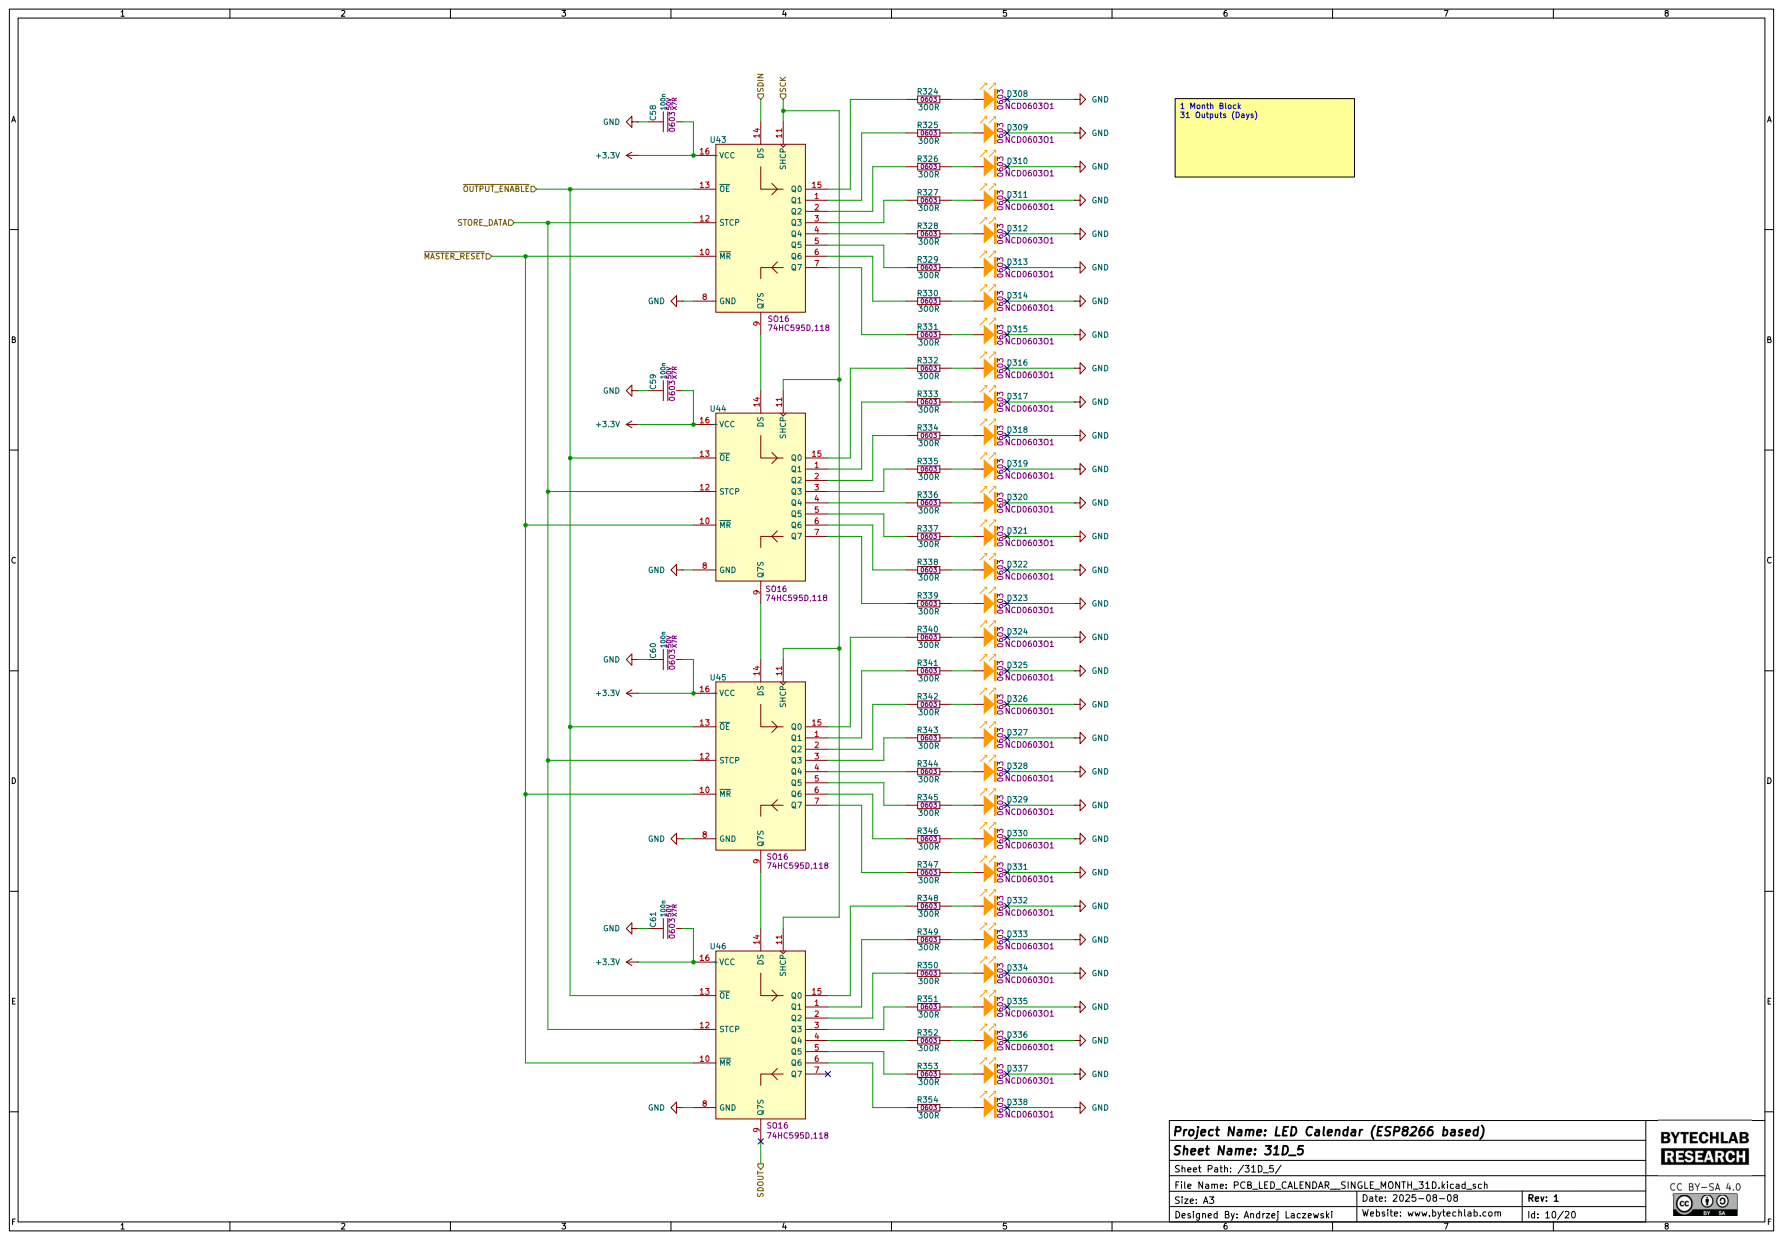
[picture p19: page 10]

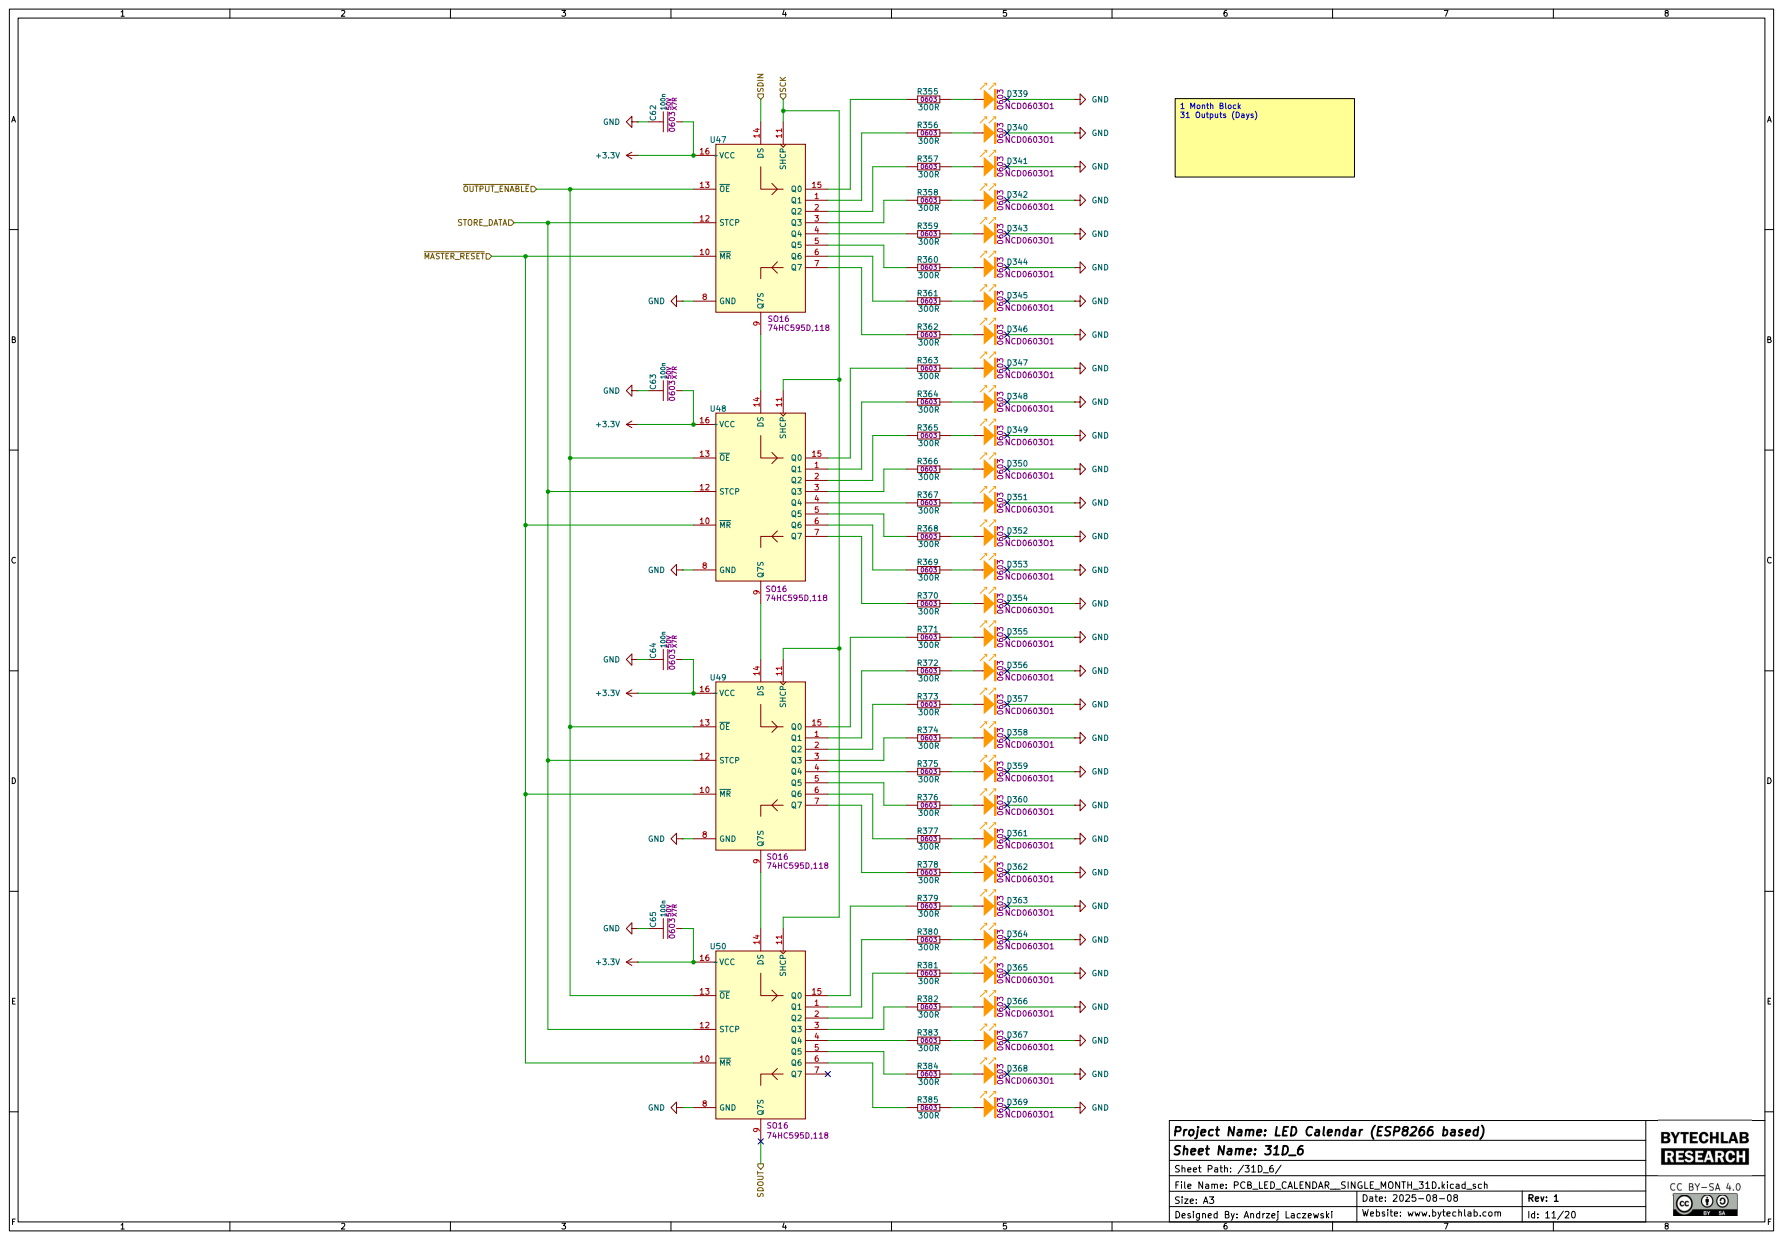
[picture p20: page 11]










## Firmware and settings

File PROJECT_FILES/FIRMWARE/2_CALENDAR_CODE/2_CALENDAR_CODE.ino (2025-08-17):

#include <ESP8266WiFi.h>
#include <NTPClient.h>
#include <WiFiUdp.h>
#include <include/WiFiState.h>

// -------- TODO -------->
// * Reduce NTP request frequency - day change prediction algorithm,
// * Compile & Libraries & Upload instructions,

// ---------------- NTP ---------------->
// Replace with your network credentials
const char *ssid     = "YOUR_SSID";
const char *password = "YOUR_PASSWD";
// Set offset time in seconds to adjust for your timezone, for example:
// GMT +1 = 3600
// GMT +8 = 28800
// GMT -1 = -3600
// GMT 0 = 0
const unsigned int NTP_Timezone_Offset = 7200; //(GMT +2)

// Define NTP Client to get time
WiFiUDP ntpUDP;
NTPClient timeClient(ntpUDP, "pool.ntp.org");

unsigned int NTP_Check_Counter = 0;
#define NTP_CHECK_EVERY_N_LOOPS 30 // 60 seconds
// ---------------- NTP ----------------<

// ---------------- LED CALENDAR ---------------->
#define LED_CALENDAR_MAX_BRIGHTNESS 230
#define LED_CALENDAR_MIN_BRIGHTNESS 254

#define PIN_LED_SCK 14
#define PIN_LED_SDOUT 13
#define PIN_LED_OE 12
#define PIN_LED_STORE_DAT 5
#define PIN_LED_MASTER_RST 4

#define SHIFT_REG_SERIAL_HALF_PERIOD 25 // 25us -> 20 kHz

unsigned int LED_Calendar_Month = 1;
unsigned int LED_Calendar_Day = 1;
unsigned int LED_Calendar_Year = 0;

unsigned int LED_Calendar_Month_old = 1;
unsigned int LED_Calendar_Day_old = 1;
unsigned int LED_Calendar_Year_old = 0;

uint8_t LED_Calendar_Year_Digit_LUT [10] = 
{
    0b11111100, // 0
    0b01100000, // 1
    0b11011010, // 2
    0b11110010, // 3
    0b01100110, // 4
    0b10110110, // 5
    0b10111110, // 6
    0b11100000, // 7
    0b11111110, // 8
    0b11110110, // 9
};
// ---------------- LED CALENDAR ----------------<

void setup() 
{
  // Initialize Serial Monitor
  Serial.begin(115200);

  Serial.println("<--------- LED CALENDAR STARTUP --------->");

  LED_Calendar_Setup();
  LED_Calendar_Check_Ambient_Light();

  LED_Calendar_Clear_All_Leds();
  LED_Calendar_Startup_Animation();
  LED_Calendar_Clear_All_Leds();

  NTP_Setup();
  NTP_Update_Time_Variables();
}

void loop()
{
  if (NTP_Check_Counter >= NTP_CHECK_EVERY_N_LOOPS)
  {
    NTP_Update_Time_Variables();
    NTP_Check_Counter = 0;
  }
  else
  {
    NTP_Check_Counter++;
  }
  
  LED_Calendar_Check_Ambient_Light();

  if( LED_Calendar_Month != LED_Calendar_Month_old || LED_Calendar_Day != LED_Calendar_Day_old || LED_Calendar_Year != LED_Calendar_Year_old )
  {
    Serial.println("New date received --> Updating LEDs");
    LED_Calendar_Write_Date_To_LEDs_Animation();

    LED_Calendar_Month_old = LED_Calendar_Month;
    LED_Calendar_Day_old = LED_Calendar_Day;
    LED_Calendar_Year_old = LED_Calendar_Year;
  }

  
  delay(1000);
  LED_Calendar_Write_Date_Blink_Last_LED(1);
  delay(1000);
  LED_Calendar_Write_Date_Blink_Last_LED(0);
}

// ******************************************************************************************
// ******************************************************************************************

void NTP_Setup (void)
{
  // Connect to Wi-Fi
  Serial.print("Connecting to ");
  Serial.println(ssid);
  WiFi.begin(ssid, password);
  while (WiFi.status() != WL_CONNECTED) 
  {
    delay(500);
    Serial.print(".");
  }
  Serial.println("");
  // Initialize a NTPClient to get time
  timeClient.begin();
  timeClient.setTimeOffset(NTP_Timezone_Offset);
}

void LED_Calendar_Setup (void)
{
  pinMode(PIN_LED_SCK, OUTPUT);
  pinMode(PIN_LED_STORE_DAT, OUTPUT);

  pinMode(PIN_LED_SDOUT, OUTPUT);
  pinMode(PIN_LED_OE, OUTPUT);
  pinMode(PIN_LED_MASTER_RST, OUTPUT);

  //--------------------------------

  digitalWrite(PIN_LED_MASTER_RST, HIGH);

  analogWriteFreq(20000); // 20 kHz
  analogWrite(PIN_LED_OE, 254); // init PWM to lowest brightness
}


void NTP_Update_Time_Variables(void)
{
  timeClient.update();

  time_t epochTime = timeClient.getEpochTime();
  Serial.print("Epoch Time: ");
  Serial.print(epochTime);

  int currentHour = timeClient.getHours();
  Serial.print(",Hour: ");
  Serial.print(currentHour);  

  int currentMinute = timeClient.getMinutes();
  Serial.print(",Minutes: ");
  Serial.print(currentMinute); 
   
  int currentSecond = timeClient.getSeconds();
  Serial.print(",Seconds: ");
  Serial.print(currentSecond); 

  //Get a time structure
  struct tm *ptm = gmtime ((time_t *)&epochTime); 

  LED_Calendar_Day = ptm->tm_mday;
  Serial.print(",Month day: ");
  Serial.print(LED_Calendar_Day);

  LED_Calendar_Month = ptm->tm_mon+1;
  Serial.print(",Month: ");
  Serial.print(LED_Calendar_Month);

  LED_Calendar_Year = ptm->tm_year+1900;
  Serial.print(",Year: ");
  Serial.println(LED_Calendar_Year);
}

void LED_Calendar_Write_Date_To_LEDs_Animation (void)
{
  unsigned int number_of_day_led_target = (((LED_Calendar_Month-1)*32)+LED_Calendar_Day);

  unsigned int calendar_year_digits [4] = 
  {
    (LED_Calendar_Year % 10),
    (LED_Calendar_Year / 10) % 10,
    (LED_Calendar_Year / 100) % 10,
    (LED_Calendar_Year / 1000) % 10
  };

  for (unsigned int number_of_day_led = 0; number_of_day_led <= number_of_day_led_target; number_of_day_led++ )
  {
    for (unsigned int ii = 0 ; ii < 4 ; ii++)
    {
      uint8_t single_digit_bits = LED_Calendar_Year_Digit_LUT [calendar_year_digits[ii]];
      for (unsigned int i = 0 ; i < 8 ; i++)
      {
        
        if ((single_digit_bits & 0b00000001) == 0b00000001)
        {
          digitalWrite(PIN_LED_SDOUT, HIGH);
        }
        else
        {
          digitalWrite(PIN_LED_SDOUT, LOW);
        }
        digitalWrite(PIN_LED_SCK, LOW);
        yield();
        delayMicroseconds(SHIFT_REG_SERIAL_HALF_PERIOD);  
        digitalWrite(PIN_LED_SCK, HIGH);
        yield();
        delayMicroseconds(SHIFT_REG_SERIAL_HALF_PERIOD); 
        single_digit_bits = single_digit_bits >> 1;
      }
    }

    // Fill days with 0's
    digitalWrite(PIN_LED_SDOUT, LOW);
    for (unsigned int i = 0 ; i < (384-number_of_day_led) ; i++)
    {
      digitalWrite(PIN_LED_SCK, LOW);
      yield();
      delayMicroseconds(SHIFT_REG_SERIAL_HALF_PERIOD);  
      digitalWrite(PIN_LED_SCK, HIGH);
      yield();
      delayMicroseconds(SHIFT_REG_SERIAL_HALF_PERIOD); 
    }

    // Fill days with 1's
    digitalWrite(PIN_LED_SDOUT, HIGH);
    for (unsigned int i = 0 ; i < number_of_day_led ; i++)
    {
      digitalWrite(PIN_LED_SCK, LOW);
      yield();
      delayMicroseconds(SHIFT_REG_SERIAL_HALF_PERIOD);  
      digitalWrite(PIN_LED_SCK, HIGH);
      yield();
      delayMicroseconds(SHIFT_REG_SERIAL_HALF_PERIOD);  
    }

    digitalWrite(PIN_LED_SDOUT, LOW);

    // Latch data
    yield();
    delayMicroseconds(SHIFT_REG_SERIAL_HALF_PERIOD);                      
    digitalWrite(PIN_LED_STORE_DAT, LOW); 
    yield();
    delayMicroseconds(SHIFT_REG_SERIAL_HALF_PERIOD); 
    digitalWrite(PIN_LED_STORE_DAT, HIGH);
  }
}

void LED_Calendar_Write_Date_Blink_Last_LED (unsigned int last_led_onoff)
{
  unsigned int number_of_day_led = (((LED_Calendar_Month-1)*32)+LED_Calendar_Day) - last_led_onoff;

  unsigned int calendar_year_digits [4] = 
  {
    (LED_Calendar_Year % 10),
    (LED_Calendar_Year / 10) % 10,
    (LED_Calendar_Year / 100) % 10,
    (LED_Calendar_Year / 1000) % 10
  };

  for (unsigned int ii = 0 ; ii < 4 ; ii++)
  {
    uint8_t single_digit_bits = LED_Calendar_Year_Digit_LUT [calendar_year_digits[ii]];
    for (unsigned int i = 0 ; i < 8 ; i++)
    {
      
      if ((single_digit_bits & 0b00000001) == 0b00000001)
      {
        digitalWrite(PIN_LED_SDOUT, HIGH);
      }
      else
      {
        digitalWrite(PIN_LED_SDOUT, LOW);
      }
      digitalWrite(PIN_LED_SCK, LOW);
      yield();
      delayMicroseconds(SHIFT_REG_SERIAL_HALF_PERIOD);  
      digitalWrite(PIN_LED_SCK, HIGH);
      yield();
      delayMicroseconds(SHIFT_REG_SERIAL_HALF_PERIOD); 
      single_digit_bits = single_digit_bits >> 1;
    }
  }

  // Fill days with 0's
  digitalWrite(PIN_LED_SDOUT, LOW);
  for (unsigned int i = 0 ; i < (384-number_of_day_led) ; i++)
  {
    digitalWrite(PIN_LED_SCK, LOW);
    yield();
    delayMicroseconds(SHIFT_REG_SERIAL_HALF_PERIOD);  
    digitalWrite(PIN_LED_SCK, HIGH);
    yield();
    delayMicroseconds(SHIFT_REG_SERIAL_HALF_PERIOD); 
  }

  // Fill days with 1's
  digitalWrite(PIN_LED_SDOUT, HIGH);
  for (unsigned int i = 0 ; i < number_of_day_led ; i++)
  {
    digitalWrite(PIN_LED_SCK, LOW);
    yield();
    delayMicroseconds(SHIFT_REG_SERIAL_HALF_PERIOD);  
    digitalWrite(PIN_LED_SCK, HIGH);
    yield();
    delayMicroseconds(SHIFT_REG_SERIAL_HALF_PERIOD);  
  }

  digitalWrite(PIN_LED_SDOUT, LOW);

  // Latch data
  yield();
  delayMicroseconds(SHIFT_REG_SERIAL_HALF_PERIOD);                      
  digitalWrite(PIN_LED_STORE_DAT, LOW); 
  yield();
  delayMicroseconds(SHIFT_REG_SERIAL_HALF_PERIOD); 
  digitalWrite(PIN_LED_STORE_DAT, HIGH);
  
}

void LED_Calendar_Check_Ambient_Light (void)
{
  unsigned int ambient_light_intensity = analogRead(A0);
  analogWrite(PIN_LED_OE, map(ambient_light_intensity,0,600,LED_CALENDAR_MIN_BRIGHTNESS,LED_CALENDAR_MAX_BRIGHTNESS));
  Serial.print("Ambient Light Intensity = ");
  Serial.println(ambient_light_intensity);
}

void LED_Calendar_Startup_Animation (void)
{
  for ( unsigned int num_of_on_leds = 0 ; num_of_on_leds < 416 ; num_of_on_leds++)
  {
    // Fill days with 0's
    digitalWrite(PIN_LED_SDOUT, LOW);
    for (unsigned int i = 0 ; i < (416-num_of_on_leds) ; i++)
    {
      digitalWrite(PIN_LED_SCK, LOW);
      yield();
      delayMicroseconds(SHIFT_REG_SERIAL_HALF_PERIOD);  
      digitalWrite(PIN_LED_SCK, HIGH);
      yield();
      delayMicroseconds(SHIFT_REG_SERIAL_HALF_PERIOD);  
    }

    // Fill days with 1's
    digitalWrite(PIN_LED_SDOUT, HIGH);
    for (unsigned int i = 0 ; i < num_of_on_leds ; i++)
    {
      digitalWrite(PIN_LED_SCK, LOW);
      yield();
      delayMicroseconds(SHIFT_REG_SERIAL_HALF_PERIOD);  
      digitalWrite(PIN_LED_SCK, HIGH);
      yield();
      delayMicroseconds(SHIFT_REG_SERIAL_HALF_PERIOD);  
    }

    digitalWrite(PIN_LED_SDOUT, LOW);

    // Latch data
    yield();
    delayMicroseconds(SHIFT_REG_SERIAL_HALF_PERIOD);                     
    digitalWrite(PIN_LED_STORE_DAT, LOW); 
    yield();
    delayMicroseconds(SHIFT_REG_SERIAL_HALF_PERIOD);                     
    digitalWrite(PIN_LED_STORE_DAT, HIGH); 
  }
}

void LED_Calendar_Clear_All_Leds (void)
{
  // Fill days with 0's
  digitalWrite(PIN_LED_SDOUT, LOW);
  for (unsigned int i = 0 ; i < 416 ; i++)
  {
    digitalWrite(PIN_LED_SCK, LOW);
    yield();
    delayMicroseconds(SHIFT_REG_SERIAL_HALF_PERIOD);  
    digitalWrite(PIN_LED_SCK, HIGH);
    yield();
    delayMicroseconds(SHIFT_REG_SERIAL_HALF_PERIOD);  
  }

  digitalWrite(PIN_LED_SDOUT, LOW);

  // Latch data
  yield();
  delayMicroseconds(SHIFT_REG_SERIAL_HALF_PERIOD);                     
  digitalWrite(PIN_LED_STORE_DAT, LOW); 
  yield();
  delayMicroseconds(SHIFT_REG_SERIAL_HALF_PERIOD);                     
  digitalWrite(PIN_LED_STORE_DAT, HIGH); 
  
}

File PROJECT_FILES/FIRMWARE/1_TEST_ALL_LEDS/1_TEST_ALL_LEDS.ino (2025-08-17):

#define LED_SCK 14
#define LED_SDOUT 13
#define LED_OE 12
#define LED_STORE_DAT 5
#define LED_MASTER_RST 4



void setup() {
  pinMode(LED_SCK, OUTPUT);
  pinMode(LED_STORE_DAT, OUTPUT);

  pinMode(LED_SDOUT, OUTPUT);
  pinMode(LED_OE, OUTPUT);
  pinMode(LED_MASTER_RST, OUTPUT);

  //--------------------------------

  digitalWrite(LED_MASTER_RST, HIGH);

  // digitalWrite(LED_OE, HIGH);
  analogWriteFreq(10000);
  analogWrite(LED_OE, 254);

  digitalWrite(LED_SDOUT, HIGH);

  int i = 0;
    for ( i= 0 ; i<= 500 ; i++)
    {
      digitalWrite(LED_SCK, HIGH);
      delay(1);  
      digitalWrite(LED_SCK, LOW);
      delay(1);  
    }

  delay(10);                     
  digitalWrite(LED_STORE_DAT, LOW); 
  delay(10);                     
  digitalWrite(LED_STORE_DAT, HIGH); 
  
}

// the loop function runs over and over again forever
void loop() {


}

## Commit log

2025-08-17 Uplaod files
    [3DP_PLA_Back_Cover.ipt, 3DP_PLA_Back_Cover.stl, 3DP_PLA_Front_Mounting_Bracket.ipt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]
2026-10-31 Upload new script with less frequent NTP request (more power efficient, less network traffic)
